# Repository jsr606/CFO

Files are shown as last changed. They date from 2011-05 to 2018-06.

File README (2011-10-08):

source files for the CHEAP, FAT and OPEN project
===========================================================================
more info: http://8bitklubben.dk/project/CFO/
===========================================================================
in this repository you will find code for the CFO synth ("arduino" folder), the CFO tracker ("processing" folder), illustrator files for the acryl casing ("acrylic casing and lasercutter fix for PCB" folder), and CAD files for the hardware design ("eagle" folder)

sound code + hardware design in this project is based on the arduino synthesizer kit by critter and guittari: http://www.critterandguitari.com/content/arduino-synthesizer-kit

PLEASE NOTE:
this is a work in progress: all code and hardware design still consist bugs. dig the glitches! njam njam!

--- enjoy
          _____                    _____                   _______         
         /\    \                  /\    \                 /::\    \        
        /::\    \                /::\    \               /::::\    \       
       /::::\    \              /::::\    \             /::::::\    \      
      /::::::\    \            /::::::\    \           /::::::::\    \     
     /:::/\:::\    \          /:::/\:::\    \         /:::/~~\:::\    \    
    /:::/  \:::\    \        /:::/__\:::\    \       /:::/    \:::\    \   
   /:::/    \:::\    \      /::::\   \:::\    \     /:::/    / \:::\    \  
  /:::/    / \:::\    \    /::::::\   \:::\    \   /:::/____/   \:::\____\ 
 /:::/    /   \:::\    \  /:::/\:::\   \:::\    \ |:::|    |     |:::|    |
/:::/____/     \:::\____\/:::/  \:::\   \:::\____\|:::|____|     |:::|    |
\:::\    \      \::/    /\::/    \:::\   \::/    / \:::\    \   /:::/    / 
 \:::\    \      \/____/  \/____/ \:::\   \/____/   \:::\    \ /:::/    /  
  \:::\    \                       \:::\    \        \:::\    /:::/    /   
   \:::\    \                       \:::\____\        \:::\__/:::/    /    
    \:::\    \                       \::/    /         \::::::::/    /     
     \:::\    \                       \/____/           \::::::/    /      
      \:::\    \                                         \::::/    /       
       \:::\____\                                         \::/____/        
        \::/    /                                          ~~              
         \/____/

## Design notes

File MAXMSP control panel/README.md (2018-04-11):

control panel for the CFO BODYSEQ, HÅRNET (and other teensy based CFOs)
=======================================================================

this dashboard sends the appropriate MIDI commands to the CFO synth to change most sound parameters in a user-friendly way

you will require either max/msp (free trial) or max runtime (free) to run this: http://cycling74.com/downloads/

to get started:
1. connect you CFO
2. click the "Update Lists" button - this will populate the list of possible MIDI inputs and outputs
3. choose: Out: Teensy MIDI
4. make sounds! (please note the control panel does not generate MIDI notes, it only sets up the synthesis engine. to play notes, you either have to do this with the synth itself or via MIDI sequencing from a DAW or something similar)
5. to save or recall presets select bank U/A/B/C (U is user presets, will be saved to CFO EEPROM, and can be restored after power off)

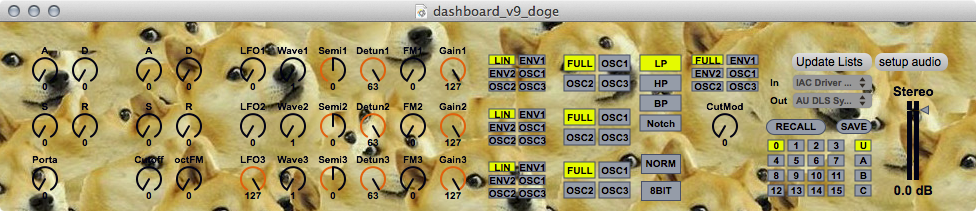
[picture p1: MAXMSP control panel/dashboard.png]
control panel preview


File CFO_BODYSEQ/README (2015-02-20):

CFO BODYSEQ
===========
the CFO BODYSEQ is a step sequencer and synthesizer in one. based on the arduino compatible teensy platform, the CFO BODYSEQ is fully software customizable and ready to jam. the synth is a raw digital acid machine, with an 8 step touch responsive interface based on skin connectivity. make your sweat play for you!
http://vsionhairies.info/

schematics on upverter: https://upverter.com/videomusik/ff5b46c3e927ee1e/CFO-BODYSEQ/

assembly instructions: https://github.com/jsr606/CFO/tree/master/CFO_BODYSEQ/documentation/CFO%20BODYSEQ%203%20button%20version

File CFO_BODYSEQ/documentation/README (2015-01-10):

notes on uploading code to teensy based CFOs

- first install arduino http://arduino.cc/ + this library

- then install teensyduino: https://www.pjrc.com/teensy/teensyduino.html
you don't have to install any of the libraries

- restart arduino

- teensy settings in arduino:
board should be set to "Teensy 3.1"
CPU speed should be set to "96 MHz (overclock)"
USB type should be "MIDI"

- have fun!

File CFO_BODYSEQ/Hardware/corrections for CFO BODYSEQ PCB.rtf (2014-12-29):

corrections for CFO BODYSEQ PCB
===============================
volume knob goes the wrong way
diode D11 should show polarity on print
IC socket should show orientation on print

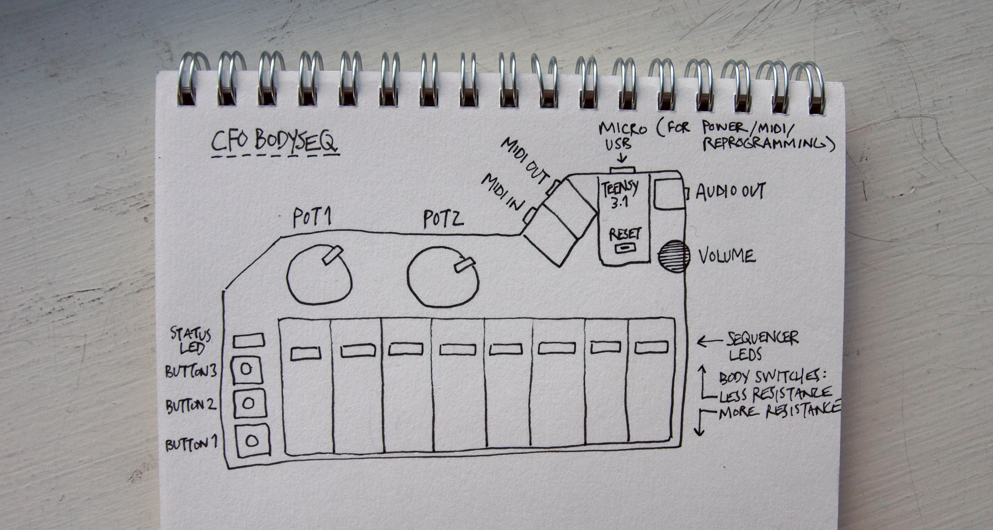
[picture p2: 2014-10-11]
CFO_BODYSEQ/documentation/CFO BODYSEQ 3 button version/manual 3 button version.rtfd/OVERVIEW CFO BODYSEQ 3 button version.JPG

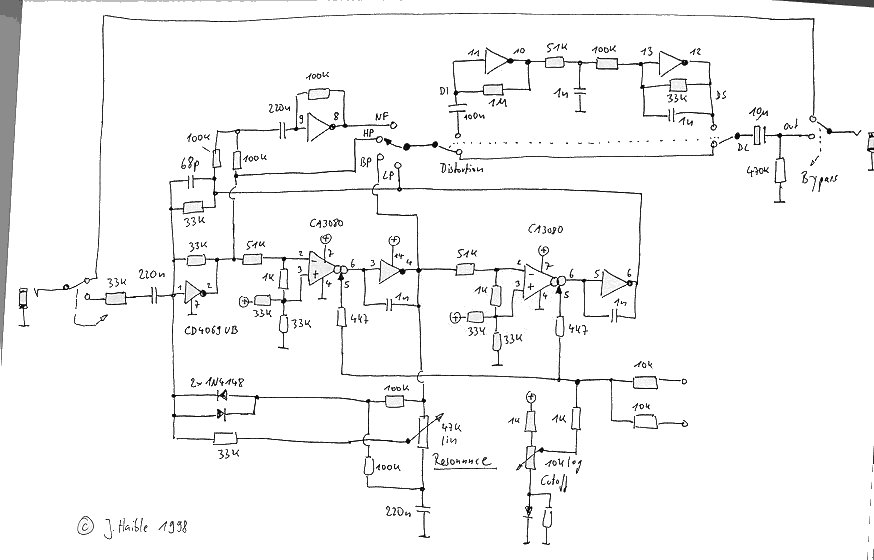
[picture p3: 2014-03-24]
CFO_Haarnet/documentation/Filter Types/hj_wasp.jpg

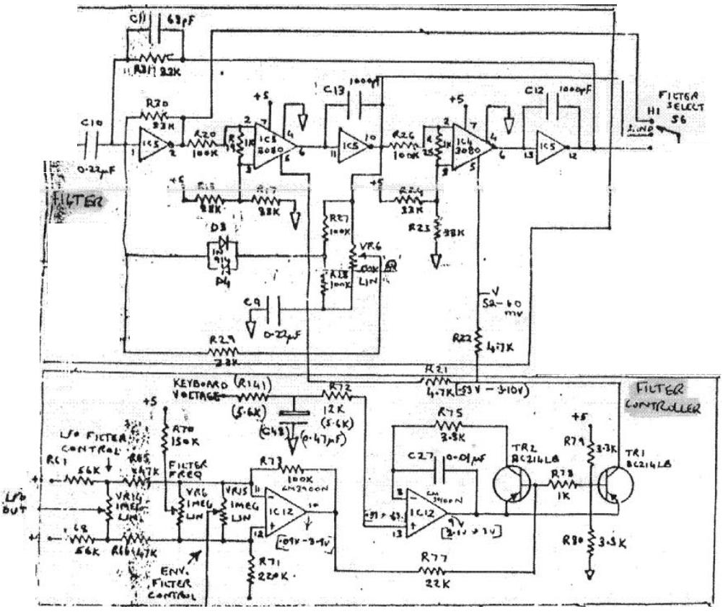
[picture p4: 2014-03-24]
CFO_Haarnet/documentation/Filter Types/wasp_org.jpg

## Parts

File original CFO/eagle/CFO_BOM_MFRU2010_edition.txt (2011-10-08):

CFO partlist - edited by hand, non-parts (pads etcs) removed, non-eagle parts added
==========================================================================================
this version for CFO MFRU edition 2010, manSEDANse workshop 2011, 4/10-2011
==========================================================================================
Exported from CFO rev 1.5_bak_jsr.brd at 6/15/11 21:39 
==========================================================================================
x Part               Value          Package       Library                  Position (mm)         Orientation

x DIST               switch         1X03/90       pinhead                  (140.5 51)            R270
x BASS               switch         1X03/90       pinhead                  (140.5 43.5)          R270

x C2                 22p            C050-025X075  rcl                      (71.1519 72.3128)     R90
x C3                 22p            C050-025X075  rcl                      (55.8893 72.3406)     R90
x C10                10nF           C050-025X075  rcl                      (115.5633 11.3685)    R270
x CL3                33n            C050-025X075  rcl                      (96.15 34.1)          R0
x CL2                47n            C050-025X075  rcl                      (124.85 34)           R0
x C1                 100n           C050-025X075  rcl                      (74.7393 72.2982)     R270
x C4                 100n           C050-025X075  rcl                      (78.092 72.3306)      R270
x C5                 100n           C050-025X075  rcl                      (18.8987 74.8509)     R90
x C8                 100n           C050-025X075  rcl                      (109.9672 11.3168)    R270
x C9                 100n           C050-025X075  rcl                      (126.5078 11.4433)    R90
x CL_IN              2u2            E2,5-6        blushingboy_experimental (125.7 21.6)          R180
x CL4                10u            E2,5-6        blushingboy_experimental (104 29)              R270
x C6                 100u           E3,5-8        rcl                      (11.4949 75.444)      R270
x C7                 100u           E3,5-8        rcl                      (11.4997 65.9713)     R90
x CL5                330u           E2,5-6        blushingboy_experimental (123 28)              R0
x CL6                10u            E2,5-6        blushingboy_experimental (-18 -37)             R0

x CONTRAST           4.7k           TRIM_POT_PTH  SparkFun                 (38.6519 43.9962)     R90
x D1                 1N4004         DO41-10       diode                    (4.3209 76.2091)      R90
x DC1                DC21MMX        DC-21MM       powersupply              (-6.4416 81.6708)     R90
x ENCODER            EC12E_SW       ALPS_EC12E_SW switch-alps              (136.4057 63.7769)    R270
x EXPRESSION_CONTROL PG203J         PG203J        con-hirschmann           (-1.2408 48.6537)     R0
x STYLOPHONE         PG203J         PG203J        con-hirschmann           (139.1984 -0.5876)    R180
x AUDIO_OUT          PG203J         PG203J        con-hirschmann           (139.2529 18.019)     R180
x IC1                ATMEGA         DIL28-3       atmel                    (69.4941 60.211)      R180
x IC3                74HC595N       DIL16         74xx-eu                  (62.255 11.5338)      R270
x IC4                74HC595N       DIL16         74xx-eu                  (74.9049 11.5048)     R90
x IC5                               78XXL         v-reg                    (12.4506 87.9283)     R263
x ICSP               ICSP           2X03          pinhead                  (45.5541 59.4185)     R90
x IR_RX                             1X03          ir-receiver                (-6.9533 68.8385)     R90
x LCD_DISPLAY                       1X16          pinhead                  (69.8556 45.9752)     R0

x LED1                              LED5MM        led                      (11.3766 -6.294)      R270
x LED2                              LED5MM        led                      (19.2176 -3.758)      R270
x LED3                              LED5MM        led                      (27.3046 -6.611)      R270
x LED4                              LED5MM        led                      (34.7606 -6.33)       R270
x LED5                              LED5MM        led                      (42.1086 -3.819)      R270
x LED6                              LED5MM        led                      (49.2836 -6.365)      R270
x LED7                              LED5MM        led                      (55.8776 -3.773)      R270
x LED8                              LED5MM        led                      (62.8946 -6.365)      R270
x LED9                              LED5MM        led                      (70.0966 -6.338)      R270
x LED10                             LED5MM        led                      (77.2646 -3.819)      R270
x LED11                             LED5MM        led                      (84.2116 -6.325)      R270
x LED12                             LED5MM        led                      (90.9066 -3.771)      R270
x LED13                             LED5MM        led                      (97.8016 -6.325)      R270
x LED14                             LED5MM        led                      (104.8966 -3.846)     R270
x LED15                             LED5MM        led                      (112.0916 -6.325)     R270
x LED16                             LED5MM        led                      (119.3866 -6.579)     R270
x PWR_LED                           LED5MM        led                      (35.2058 67.0345)     R90
x STATUS                            LED5MM        led                      (128.7394 50.916)     R90
x IR                                LED5MM        IR led                   (128.6837 44.8888)    R90

x MCP4921                           DIL08         ic-package               (102.9774 10.4479)    R180
x NAV1               DTE6K          DTE6K         switch-misc              (2.2164 33.5436)      R0
x NAV2               DTE6K          DTE6K         switch-misc              (16.9164 5.8436)      R0
x NAV3               DTE6K          DTE6K         switch-misc              (4.4164 18.8436)      R0
x NAV4               DTE6K          DTE6K         switch-misc              (29.9164 18.8436)     R0
x NAV5               DTE6K          DTE6K         switch-misc              (16.9164 18.8436)     R0
x NAV6               DTE6K          DTE6K         switch-misc              (16.9164 31.8436)     R0

x R26                4.7            0207/10       rcl                      (91.8956 60.3816)     R270
x RL1                10             0207/10       rcl                      (123 37.5)            R180
x R7                 47             0207/10       rcl                      (123.3116 47.5153)    R270
x R6                 220            0207/10       rcl                      (19.3044 41.5376)     R0
x R10                220            0207/10       rcl                      (48.2745 20.4162)     R0
x R11                220            0207/10       rcl                      (48.2745 17.9042)     R0
x R12                220            0207/10       rcl                      (48.2745 15.3922)     R0
x R13                220            0207/10       rcl                      (48.2745 12.8802)     R0
x R14                220            0207/10       rcl                      (48.2745 10.3682)     R0
x R15                220            0207/10       rcl                      (48.2745 7.8562)      R0
x R16                220            0207/10       rcl                      (48.2745 5.3442)      R0
x R17                220            0207/10       rcl                      (48.2745 2.5782)      R0
x R18                220            0207/10       rcl                      (88.8855 2.4738)      R180
x R19                220            0207/10       rcl                      (88.8855 4.9858)      R180
x R20                220            0207/10       rcl                      (88.8855 7.4978)      R180
x R21                220            0207/10       rcl                      (88.8855 10.0098)     R180
x R22                220            0207/10       rcl                      (88.8855 12.5218)     R180
x R23                220            0207/10       rcl                      (88.8855 15.0338)     R180
x R24                220            0207/10       rcl                      (88.8855 17.5458)     R180
x R25                220            0207/10       rcl                      (88.8855 20.3118)     R180
x R27                220            0207/10       rcl                      (0.4997 -5.6694)      R180
x R28                220            0207/10       rcl                      (15.7434 -11.7184)    R162.4
x R29                220            0207/10       rcl                      (23.6382 -11.6477)    R162.2
x R30                220            0207/10       rcl                      (31.1198 -11.5191)    R163.7
x R31                220            0207/10       rcl                      (38.198 -11.5505)     R163.5
x R32                220            0207/10       rcl                      (45.213 -11.645)      R163.5
x R33                220            0207/10       rcl                      (52.4307 -11.6626)    R163.5
x R34                220            0207/10       rcl                      (59.3887 -11.7339)    R163.5
x R35                220            0207/10       rcl                      (66.4165 -11.8384)    R163.5
x R36                220            0207/10       rcl                      (73.4096 -11.911)     R163.5
x R37                220            0207/10       rcl                      (80.2467 -11.7583)    R163.5
x R38                220            0207/10       rcl                      (87.3166 -11.7976)    R163.5
x R39                220            0207/10       rcl                      (94.3397 -11.687)     R163.5
x R40                220            0207/10       rcl                      (101.2719 -11.8822)   R163.5
x R41                220            0207/10       rcl                      (108.1028 -11.8279)   R163.5
x R42                220            0207/10       rcl                      (115.035 -11.6232)    R163.5
x R43                220            0207/10       rcl                      (122.0164 -11.5153)   R163.5
x R44                220            0207/10       rcl                      (128.9589 -11.4403)   R163.5
x R45                220            0207/10       rcl                      (135.8551 -11.3387)   R163.5
x R46                220            0207/10       rcl                      (142.7963 -11.194)    R163.5
x R47                220            0207/10       rcl                      (-4.8856 18.3436)     R90
x R48                220            0207/10       rcl                      (8.4004 5.3196)       R270
x R49                220            0207/10       rcl                      (0.1144 10.3196)      R180
x R50                220            0207/10       rcl                      (33.6864 27.6216)     R0
x R51                220            0207/10       rcl                      (25.4324 32.6376)     R270
x R2                 1k             0207/10       rcl                      (29.6208 63.4541)     R270
x R8                 1k             0207/10       rcl                      (97.9502 60.3244)     R90
x R9                 1k             0207/10       rcl                      (94.9682 60.3815)     R90
x R1                 10k            0207/10       rcl                      (120.9879 11.222)     R90
x R5                 10k            0207/10       rcl                      (26.7108 63.5257)     R270
x R3                 10k            0207/10       rcl                      (123.4575 11.1547)    R270
x R52                10k            0207/10       rcl                      (-6.0524 33.7524)     R270
x R53                10k            0207/10       rcl                      (130.1744 -1.0556)    R90
x R54                10k            0207/10       rcl                      (7.9032 48.6537)      R90
x RL2                10k            0207/10       rcl                      (106.5 34)            R180
x R4                 1M             0207/10       rcl                      (118.469 11.157)      R270

x RX_ON/OFF                         1X03/90       pinhead                  (-2.5617 60.6615)     R90
x S1                                B3F-10XX      switch-omron             (35.1588 73.8796)     R180
x U$1                LM386          LM386         blushingboy_experimental (108 24)              R0
x USB-TTL                           1X06          pinhead                  (72.5876 82.5212)     R173
x XTAL               16mhz          QS            special                  (63.4763 72.233)      R180
==========================================================================================
non-eagle parts
==========================================================================================
x socket for atmega328
x cooling pad for voltage regulator
x knob for encoder
x top for knob
x 3 jumpers
x tiny 10k potentiometer for volume control
x male pin headers for LCD display
x female pin headers for LCD display
==========================================================================================

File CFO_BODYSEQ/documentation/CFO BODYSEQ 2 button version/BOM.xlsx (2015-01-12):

CFO BODYSEQ 2 BUTTON VERSION BILL OF MATERIALS
Reference | Part Description | Qty | note
AUDIO, MIDI IN, MIDI OUT | Science Friction CFO Minijack (https://upverter.com/parts/part/fa8eeb0d68dda8a9) | 3 | mini jack. NB: from special china supply
C1 | Multicomp MCPBSFC-1J104KA45 (https://upverter.com/parts/part/f3762bc8e220dfd9) | 1 | small cap.
C2 | Lelon SEA101M1CBK-0607P (Radial (large) footprint) | 1 | large radial cap.
D1, D2, D3, D4, D5, D6, D7, D8, D9, D10 | Panasonic LN842RPX | 10 | LED
D11 | Vishey 1N4148 (https://upverter.com/parts/part/6b14a46a102bcce9) | 1 | diode
IC1 | PJRC.com Teensy 3.1 (https://upverter.com/parts/part/7ecd58a203736804) | 1 | teensy
male pin header , 5 pins |  | 1
female pin header , 5 pins |  | 1
male pin header , 14 pins |  | 2
female pin header , 14 pins |  | 2
IC2 | Microchip MCP6002-I/P (https://upverter.com/parts/part/4395652a2997a55d) | 1 | IC
IC2 |  | 1 | IC socket
POT1, POT2 | TT Electronics P120PK-Y25BR10K (https://upverter.com/parts/part/ce6e7634d2037d50) | 2 | pots
POT1, POT2 |  | 2 | knobs for potentiometer
R1 - R10 | Generic Resistor (120 ohm) | 10 | LED resistors
R11, R12, R13, R14, R15, R16, R17, R18, R19, R20 | Generic Resistor (10k) | 10 | bodyswitch pulldown + op amp resistors
R21 | BI Technologies 91AR50KLF (https://upverter.com/parts/part/89d94565944c1fdd) | 1 | thumbwheel pot
R22 | Generic Resistor (1k) (Axial footprint) | 1 | color code: brown, black, red
S1, S2, | ALPS SKRGAFD010 (https://upverter.com/parts/part/52c025ccc06d267c) | 2 | tactile switches

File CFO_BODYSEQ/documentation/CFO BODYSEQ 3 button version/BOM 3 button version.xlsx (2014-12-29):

CFO BODYSEQ (3 button version) BILL OF MATERIALS
Reference | Part Description | Qty | note
AUDIO, MIDI IN, MIDI OUT | Science Friction CFO Minijack (https://upverter.com/parts/part/fa8eeb0d68dda8a9) | 3 | mini jack. NB: from special china supply | X
C1 | Multicomp MCPBSFC-1J104KA45 (https://upverter.com/parts/part/f3762bc8e220dfd9) | 1 | small cap. | X
C2 | Lelon SEA101M1CBK-0607P (Radial (large) footprint) | 1 | large radial cap. | X
D1 | Panasonic LN842RPX | 1 | LED | X
D2, D3, D4, D5, D6, D8, D9, D10 | Panasonic LN842RPX | 8 | LED | X
D11 | Vishey 1N4148 (https://upverter.com/parts/part/6b14a46a102bcce9) | 1 | diode | X
IC1 | PJRC.com Teensy 3.1 (https://upverter.com/parts/part/7ecd58a203736804) | 1 | teensy
male pin header , 5 pins |  | 1 | male pin headers | X
female pin header , 5 pins |  | 1 | female pin headers | X
male pin header , 14 pins |  | 2 | male pin headers | X
female pin header , 14 pins |  | 2 | female pin headers | X
IC2 | Microchip MCP6002-I/P (https://upverter.com/parts/part/4395652a2997a55d) | 1 | IC | X
IC2 |  | 1 | IC socket | X
POT1, POT2 | TT Electronics P120PK-Y25BR10K (https://upverter.com/parts/part/ce6e7634d2037d50) | 2 | pots | X
POT1, POT2 |  | 2 | knobs for potentiometer | X
R1 - R9 | Generic Resistor (120 ohm) | 9 | LED resistors | X
R11, R12, R13, R14, R15, R16, R17, R18 | Generic Resistor (10k) | 8 | bodyswitch pulldown resistors | X
R19 | Generic Resistor (10k) (Axial footprint) | 1 | color code: yellow, purple, orange
R20 | Generic Resistor (10k) (Axial footprint) | 1 | resistor | X
R21 | BI Technologies 91AR50KLF (https://upverter.com/parts/part/89d94565944c1fdd) | 1 | thumbwheel pot | X
R22 | Generic Resistor (1k) (Axial footprint) | 1 | color code: brown, black, red
S1, S2, S3 | ALPS SKRGAFD010 (https://upverter.com/parts/part/52c025ccc06d267c) | 3 | tactile switches | X

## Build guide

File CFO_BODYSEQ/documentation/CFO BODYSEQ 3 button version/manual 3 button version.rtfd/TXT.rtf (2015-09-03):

CFO BODYSEQUENCER (3 button version) OPERATIONS MANUAL

¬

press body switches to play notes:
harder press / moist fingers give higher pitch

press more body switches for arpeggiator mode:
while arpeggiator is playing, pot2 changes arpeggiator speed

push button 1:
start/stop sequencer

while holding button 1:
bodyswitches:
enter notes in sequencer

while holding button 2:
bodyswitches:
erase notes in sequencer
pot 1:
sequencer speed

while holding button 3:
bodyswitches:
change sequencer bank (0-7)
pot 1:
change octave
pot 2:
change preset

while holding button 1 AND button 3:
bodyswitches:
select active sequencer slice

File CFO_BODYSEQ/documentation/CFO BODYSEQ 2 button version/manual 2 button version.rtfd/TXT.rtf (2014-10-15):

CFO BODYSEQUENCER (2 button version) OPERATIONS MANUAL

¬

while holding button 1:
bodyswitches:
enter notes in sequencer

while holding button 2:
bodyswitches:
erase notes in sequencer
pot 1:
sequencer speed

while holding button 1 AND button 2:
bodyswitches:
change sequencer bank (0-7)
pot 1:
change octave
pot 2:
change preset

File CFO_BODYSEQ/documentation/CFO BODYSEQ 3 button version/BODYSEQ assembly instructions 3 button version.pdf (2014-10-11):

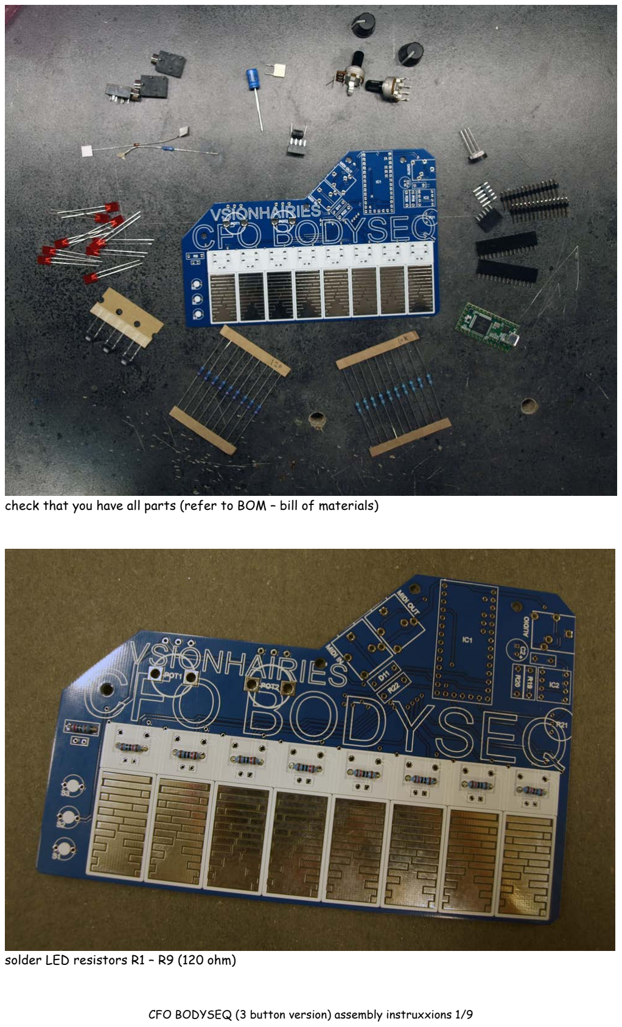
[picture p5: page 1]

CFO BODYSEQ (3 button version) assembly instruxxions 1/9 check that you have all parts (refer to BOM – bill of materials)

solder LED resistors R1 – R9 (120 ohm)

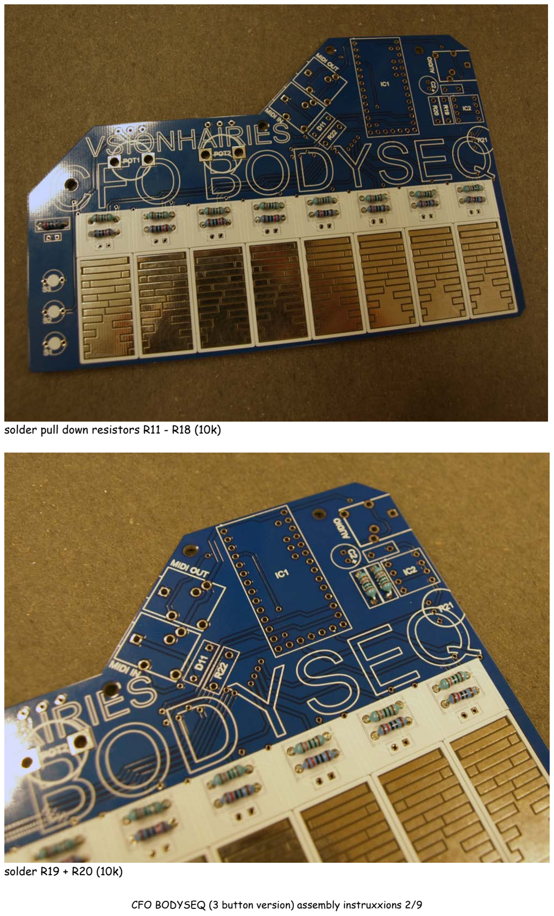
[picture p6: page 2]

solder pull down resistors R11 - R18 (10k)

solder R19 + R20 (10k)

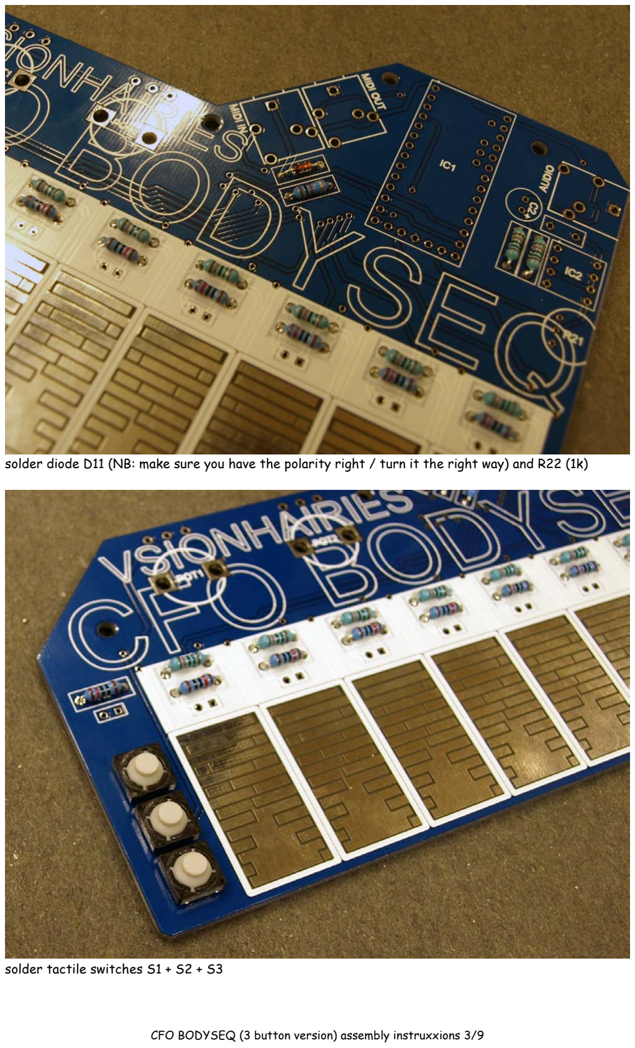
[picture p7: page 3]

solder diode D11 (NB: make sure you have the polarity right / turn it the right way) and R22 (1k)

solder tactile switches S1 + S2 + S3

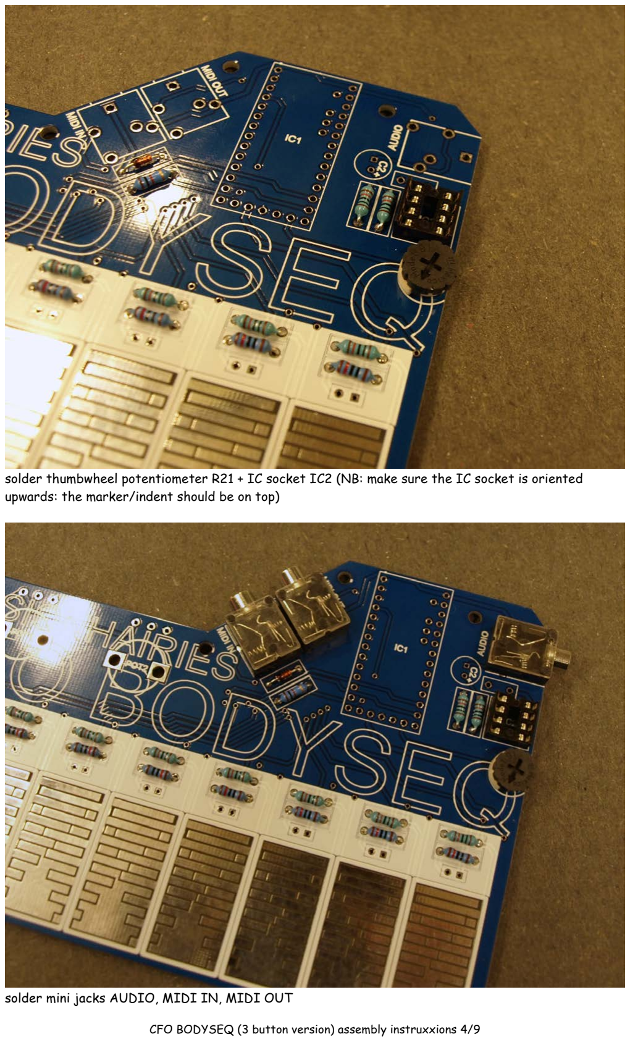
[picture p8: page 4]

solder thumbwheel potentiometer R21 + IC socket IC2 (NB: make sure the IC socket is oriented upwards: the marker/indent should be on top)

solder mini jacks AUDIO, MIDI IN, MIDI OUT

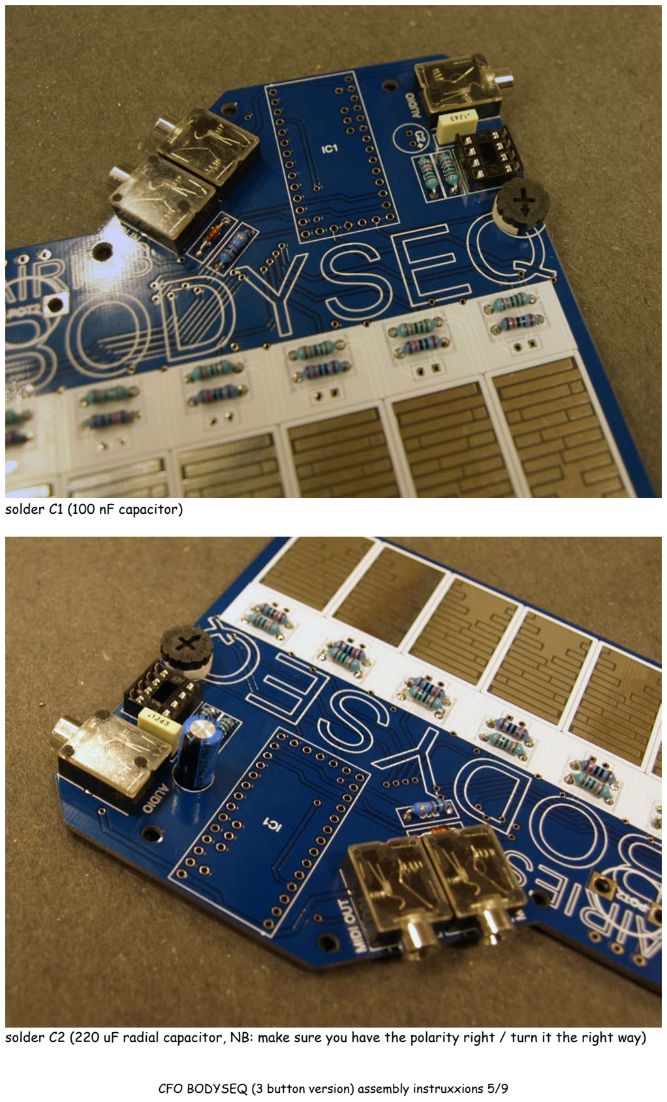
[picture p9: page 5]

solder C1 (100 nF capacitor)

solder C2 (220 uF radial capacitor, NB: make sure you have the polarity right / turn it the right way)

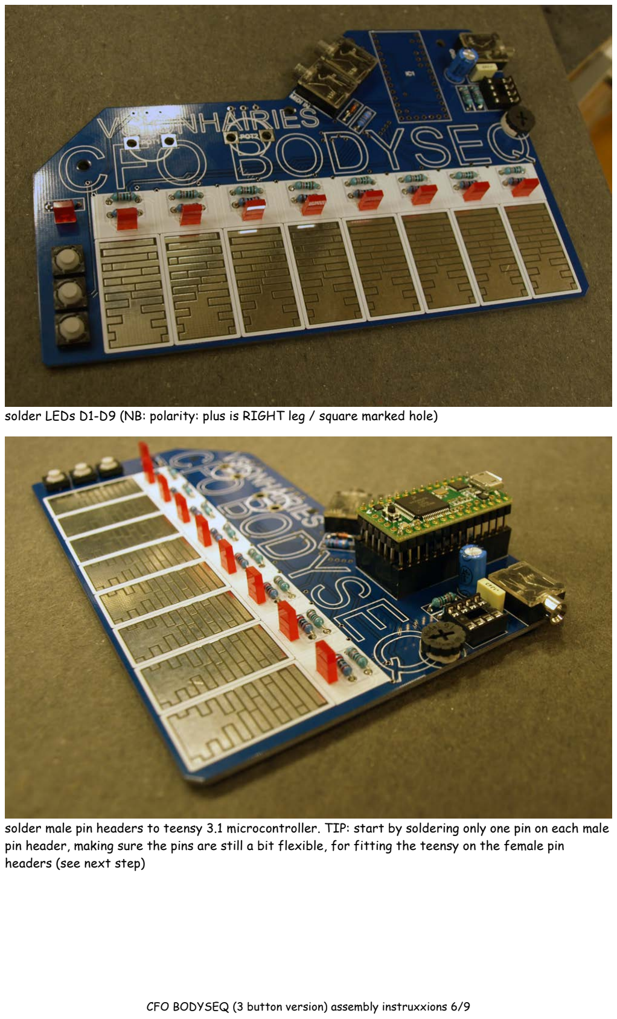
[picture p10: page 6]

solder LEDs D1-D9 (NB: polarity: plus is RIGHT leg / square marked hole)

solder male pin headers to teensy 3.1 microcontroller. TIP: start by soldering only one pin on each male pin header, making sure the pins are still a bit flexible, for fitting the teensy on the female pin headers (see next step)

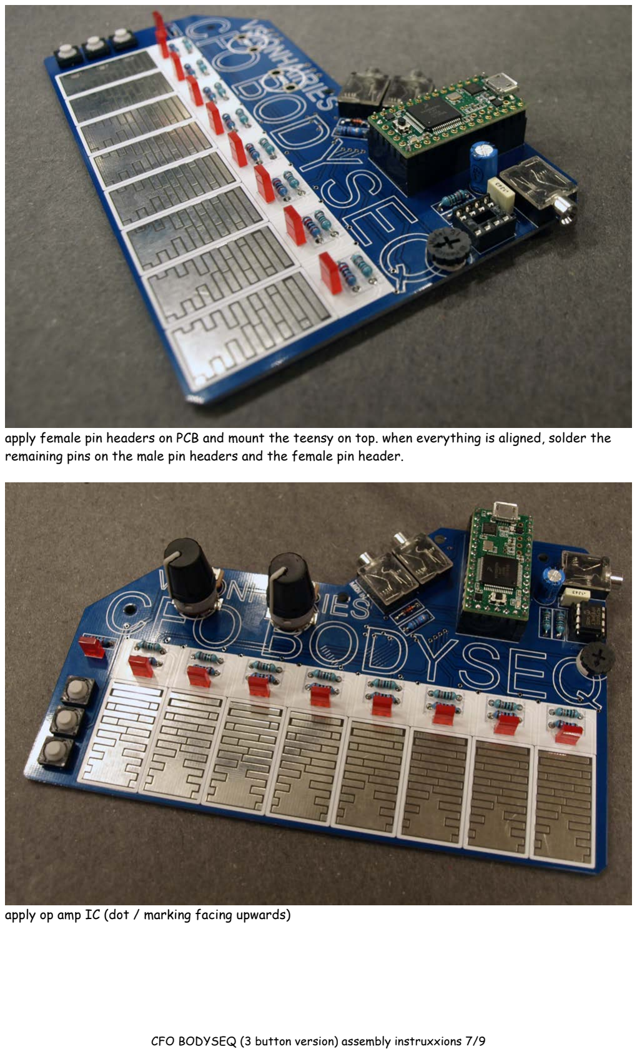
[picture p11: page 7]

apply female pin headers on PCB and mount the teensy on top. when everything is aligned, solder the remaining pins on the male pin headers and the female pin header.

apply op amp IC (dot / marking facing upwards)

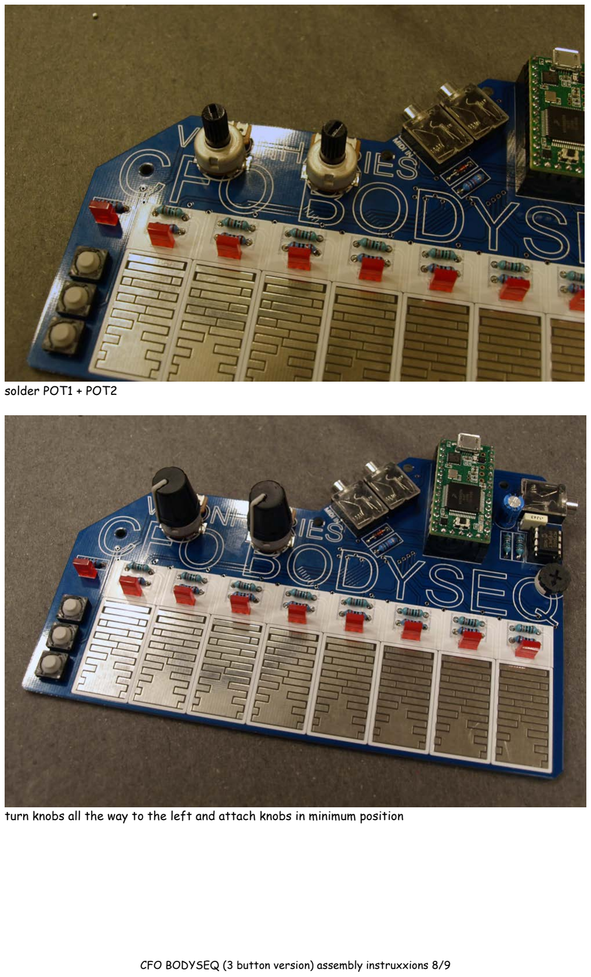
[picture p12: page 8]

solder POT1 + POT2

turn knobs all the way to the left and attach knobs in minimum position

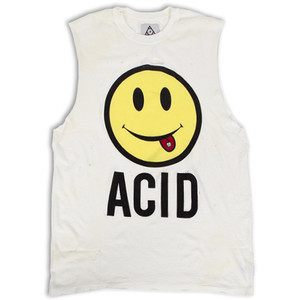
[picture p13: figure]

get dressed. its ACID TIME!

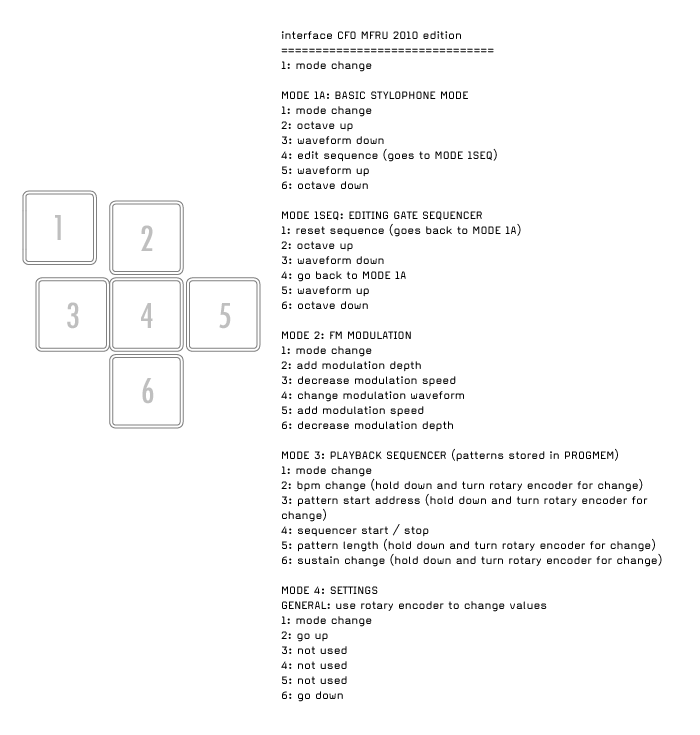
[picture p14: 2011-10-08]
original CFO/documentation/control-manual.png

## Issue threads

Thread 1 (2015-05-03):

same color resistors :(

00alis, 2015-05-03:
hello @jsr606!
for your next rounds of kits you might consider using one 4-stripes and one 5-stripes resistor.
You now deliver both 5-stripes, unfortunately 10K resistors have the same stripes but mirrored compared to 120 resistors, so we soldered them wrong and had to unsolder them all.

just a suggestion!
best <3

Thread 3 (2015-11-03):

CFO_BODYSEQ_3buttons_arp missing lastNote

kritzikratzi, 2015-11-03:
variable should be called lastNote, not lastKey in line 79:

https://github.com/jsr606/CFO/blob/master/CFO_BODYSEQ/Arduino/experimental/CFO_BODYSEQ_3buttons_arp/CFO_BODYSEQ_3buttons_arp.ino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

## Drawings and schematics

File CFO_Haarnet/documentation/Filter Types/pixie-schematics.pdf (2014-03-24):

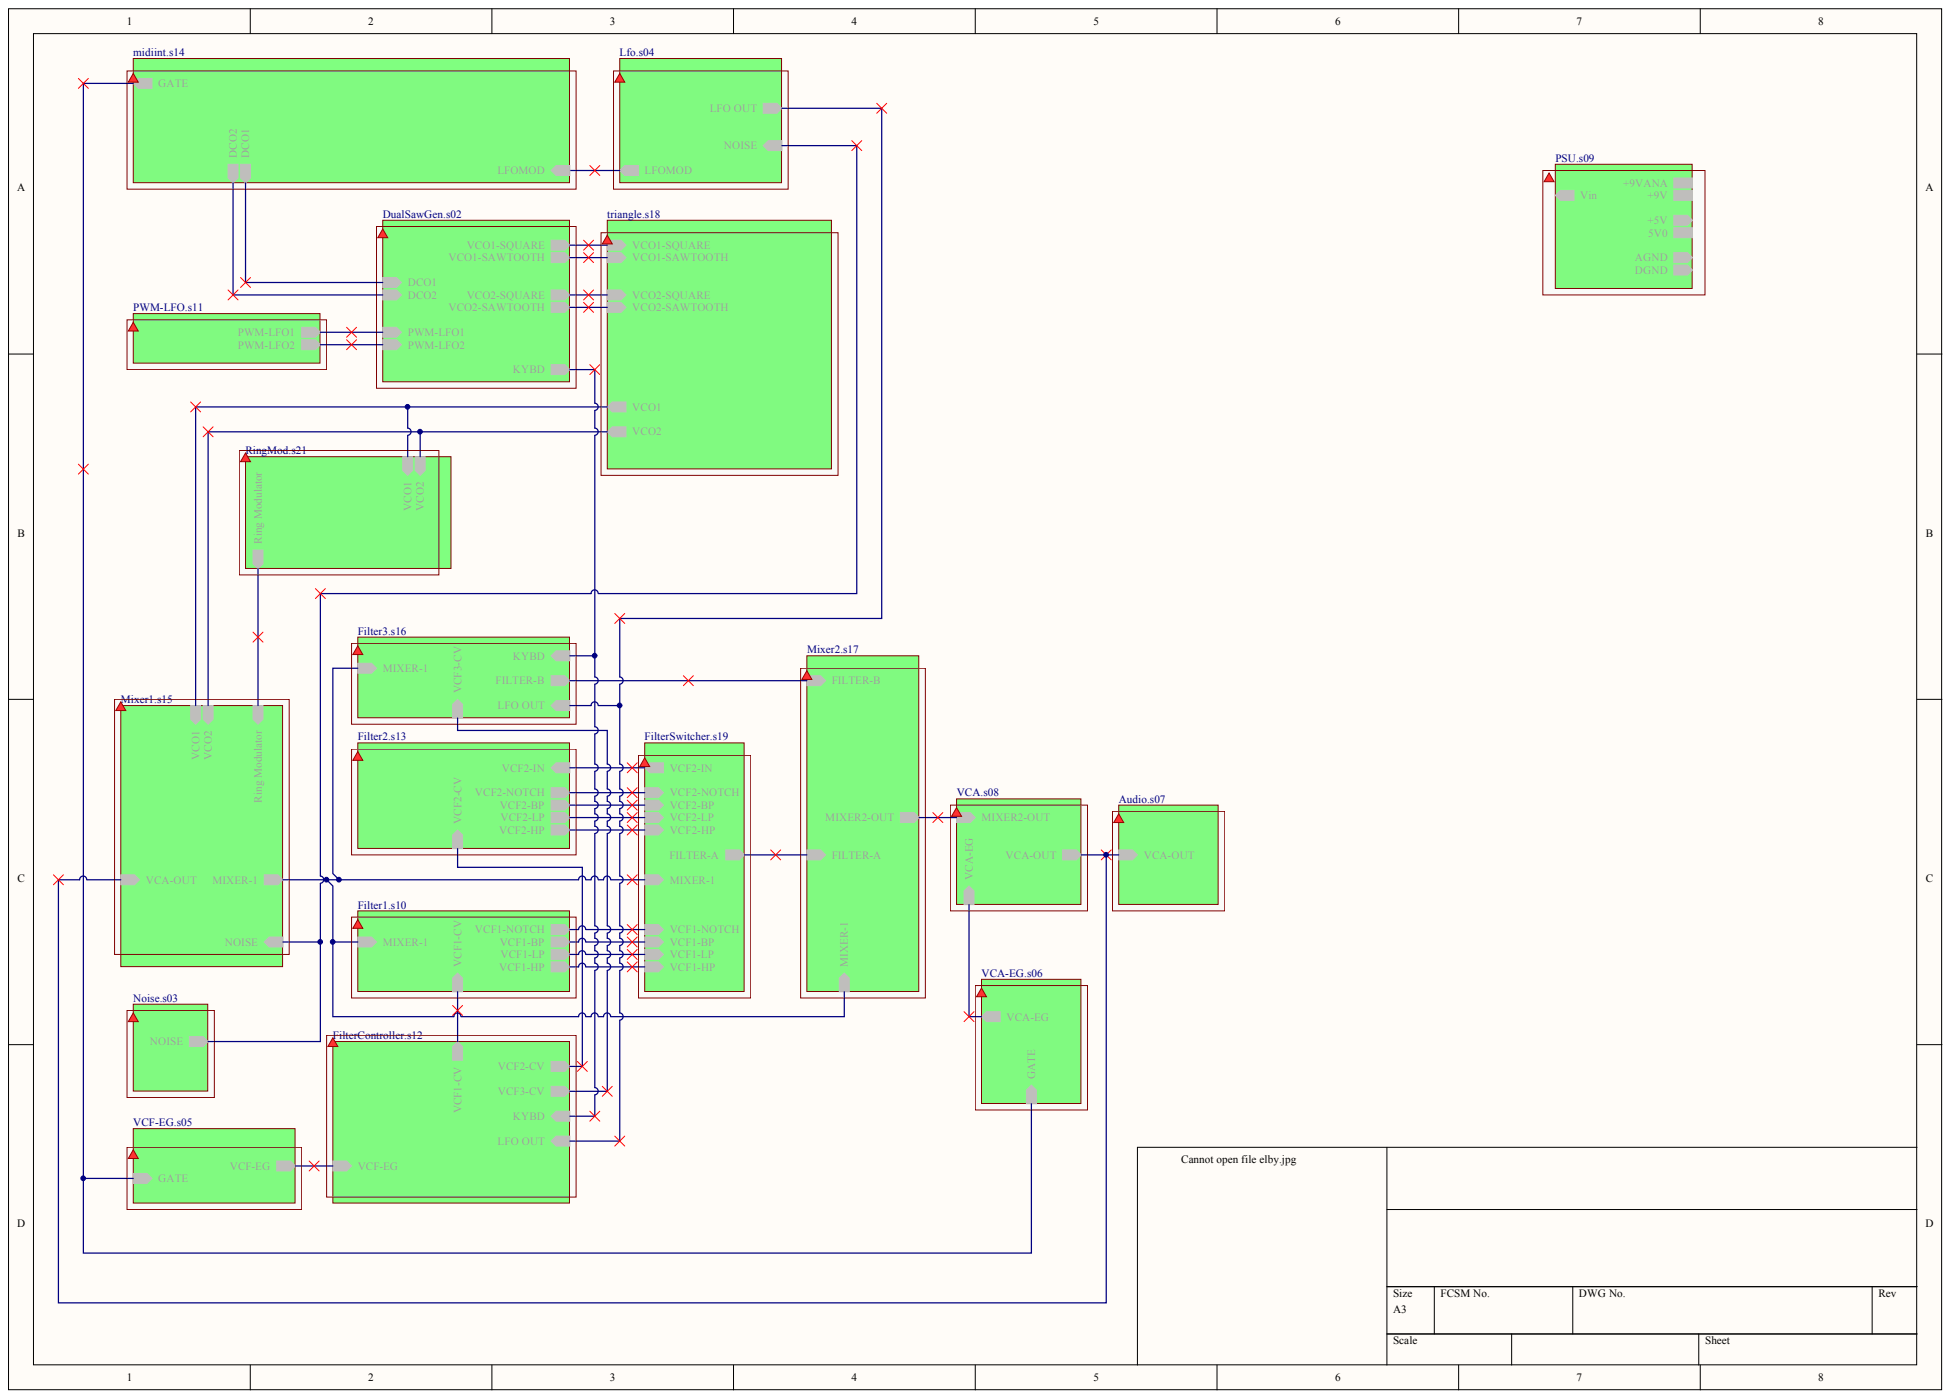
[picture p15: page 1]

LFOMOD | | LFO OUT

NOISE

LFOMOD

DualSawGen.s02 | triangle.s18

MIXER2-OUT

VCA-OUT MIXER-1 | FILTER-A MIXER-1 VCF1-NOTCH VCF1-BP VCF1-LP VCF1-HP | FILTER-A | VCA-OUT

Filter1.s10

MIXER-1 | VCF1-NOTCH VCF1-BP VCF1-LP VCF1-HP

VCA-EG.s06

VCA-EG

Cannot open file elby.jpg

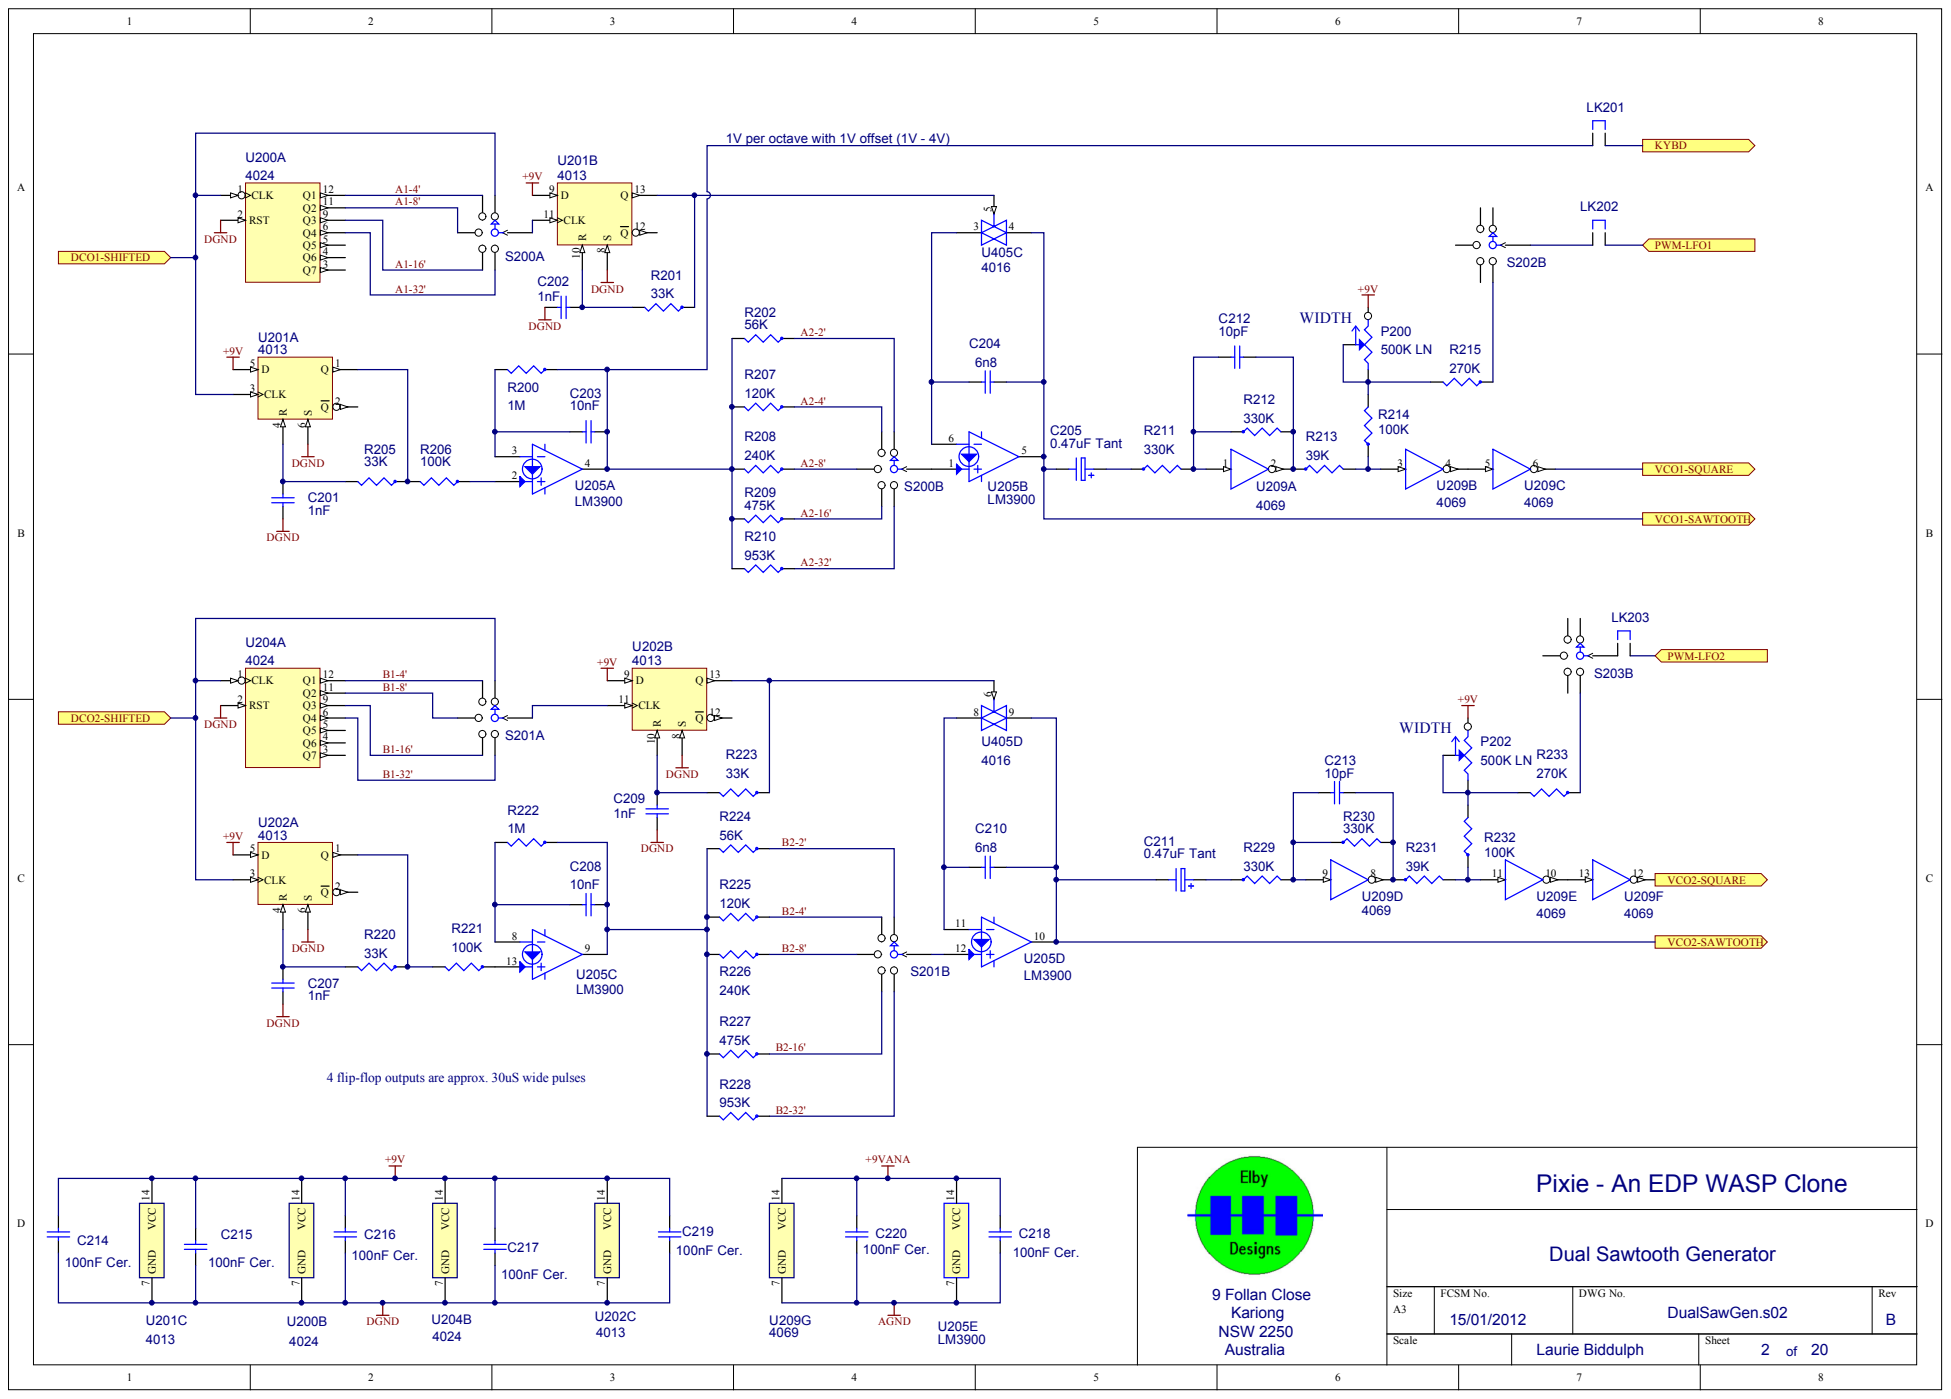
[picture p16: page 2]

1V per octave with 1V offset (1V - 4V)

4 flip-flop outputs are approx. 30uS wide pulses

Pixie - An EDP WASP Clone

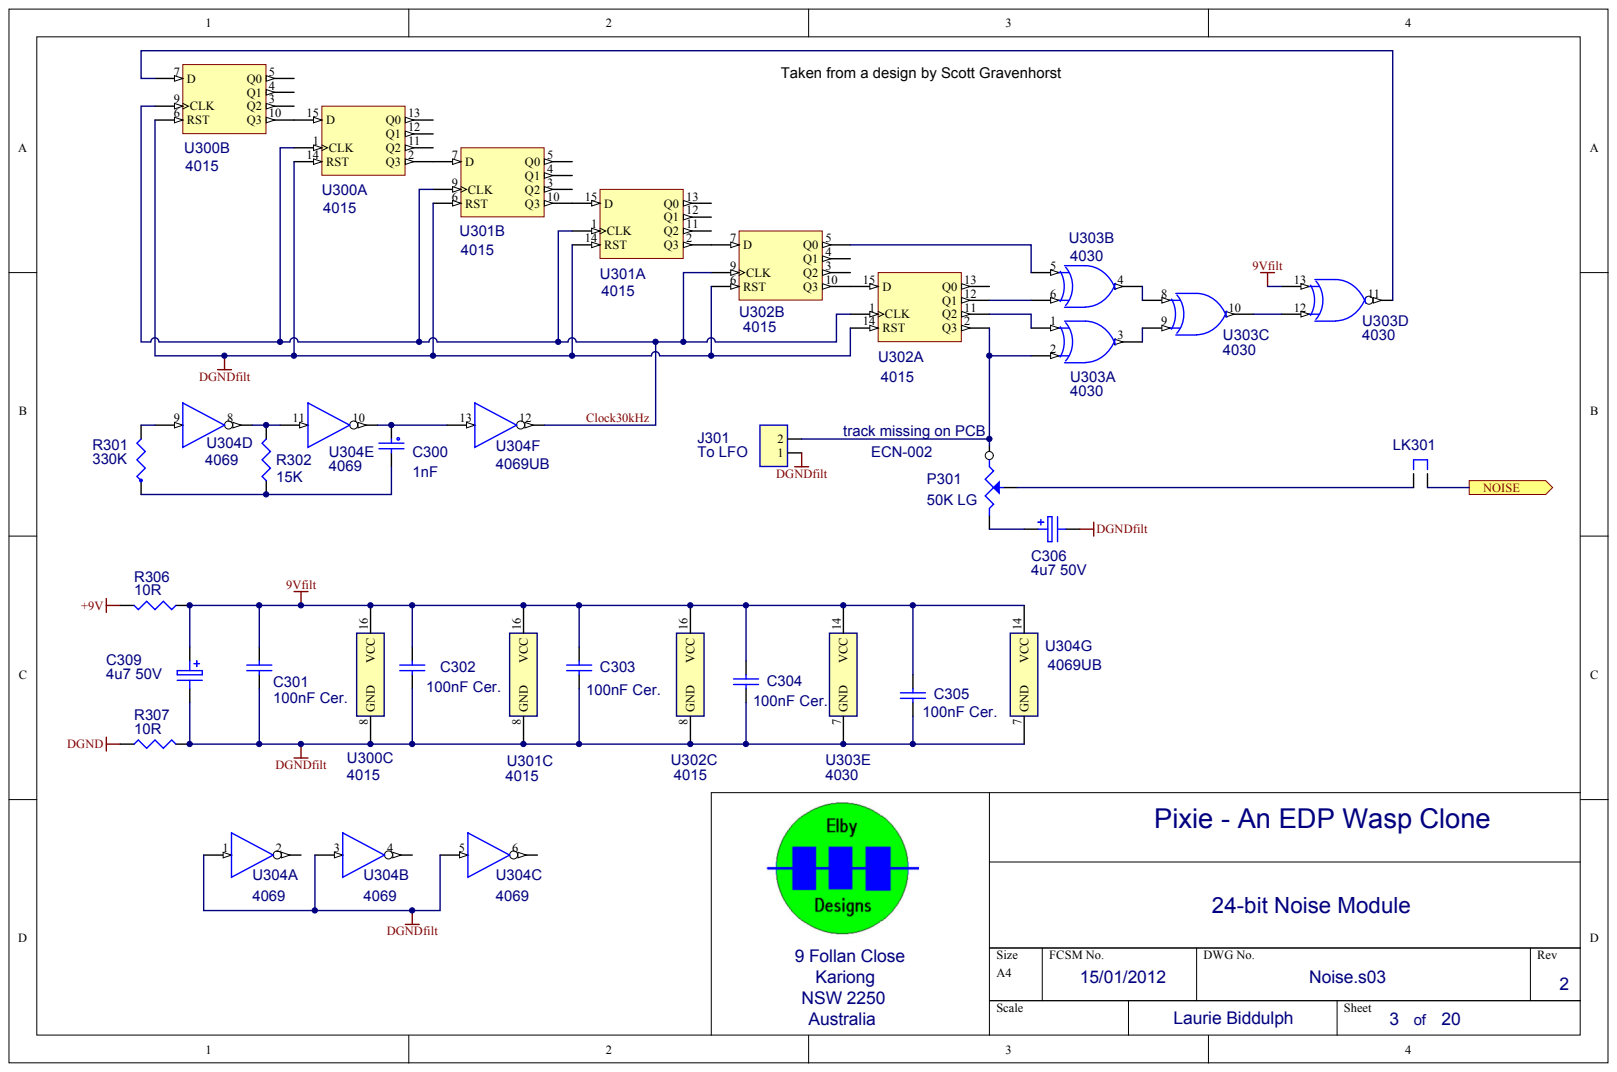
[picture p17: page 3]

Taken from a design by Scott Gravenhorst

RST 6

CLK 1

4015 | RST 14

track missing on PCB
ECN-002

Pixie - An EDP Wasp Clone

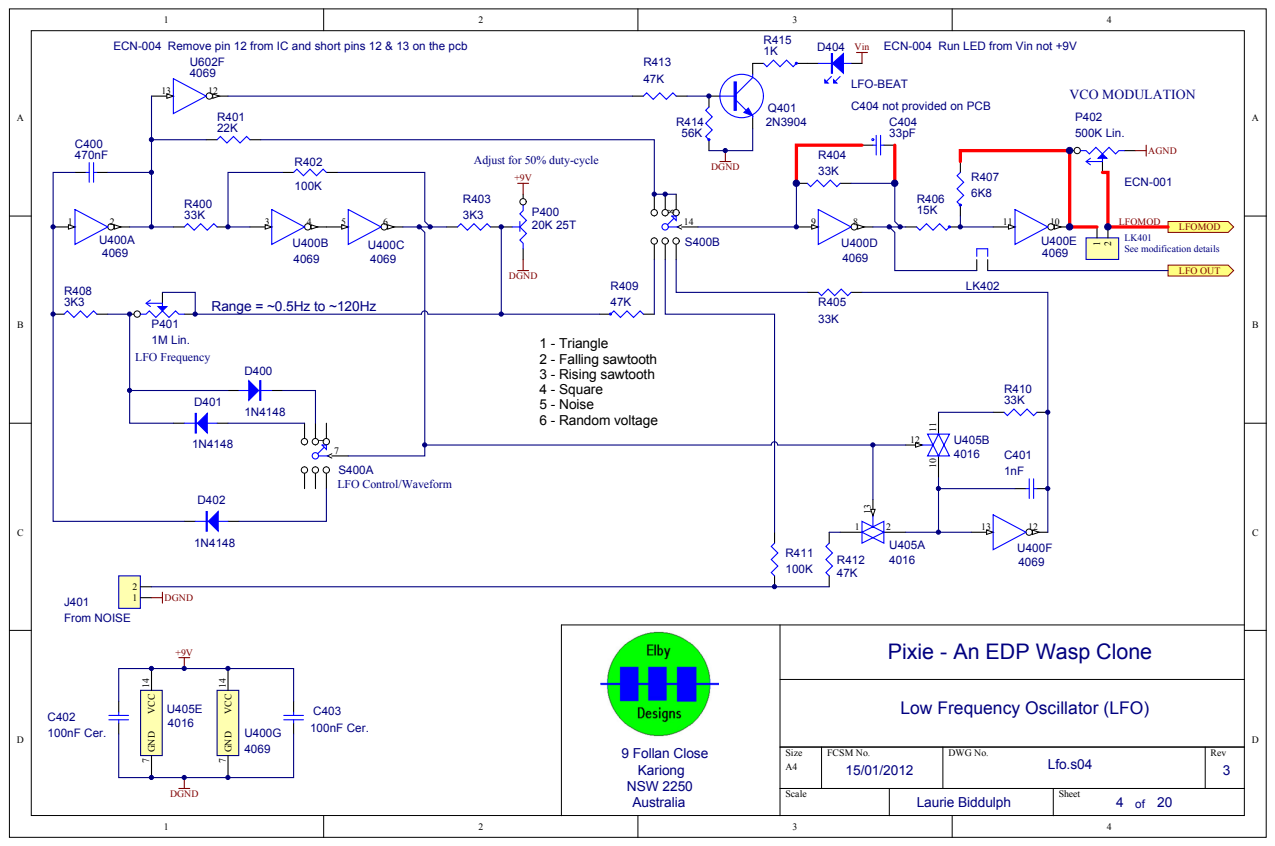
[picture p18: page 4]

C404 not provided on PCB

Adjust for 50% duty-cycle

Range = ~0.5Hz to ~120Hz

P401 1M Lin. LFO Frequency | | D400

Pixie - An EDP Wasp Clone

Low Frequency Oscillator (LFO)

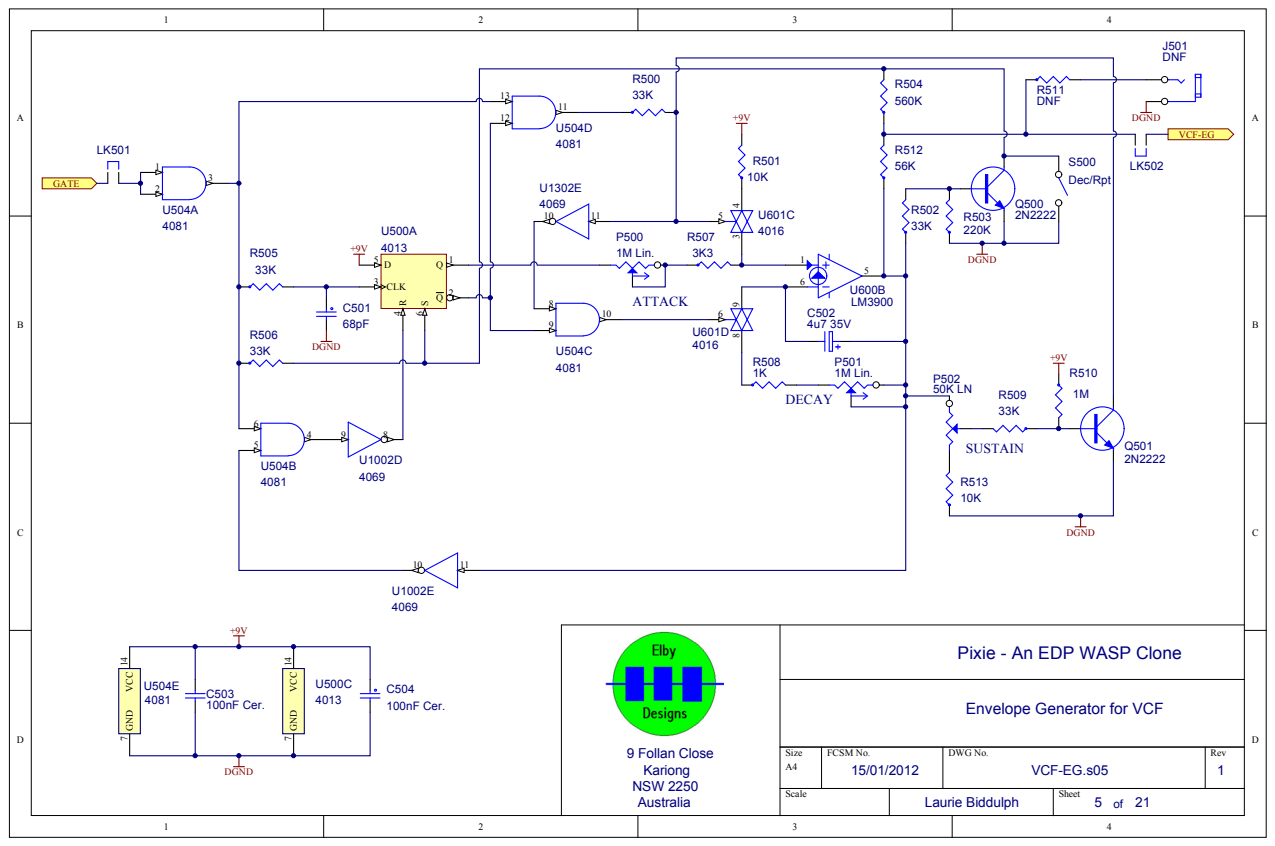
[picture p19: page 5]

CLK 3
Q | 2 R 4

Pixie - An EDP WASP Clone

Envelope Generator for VCF

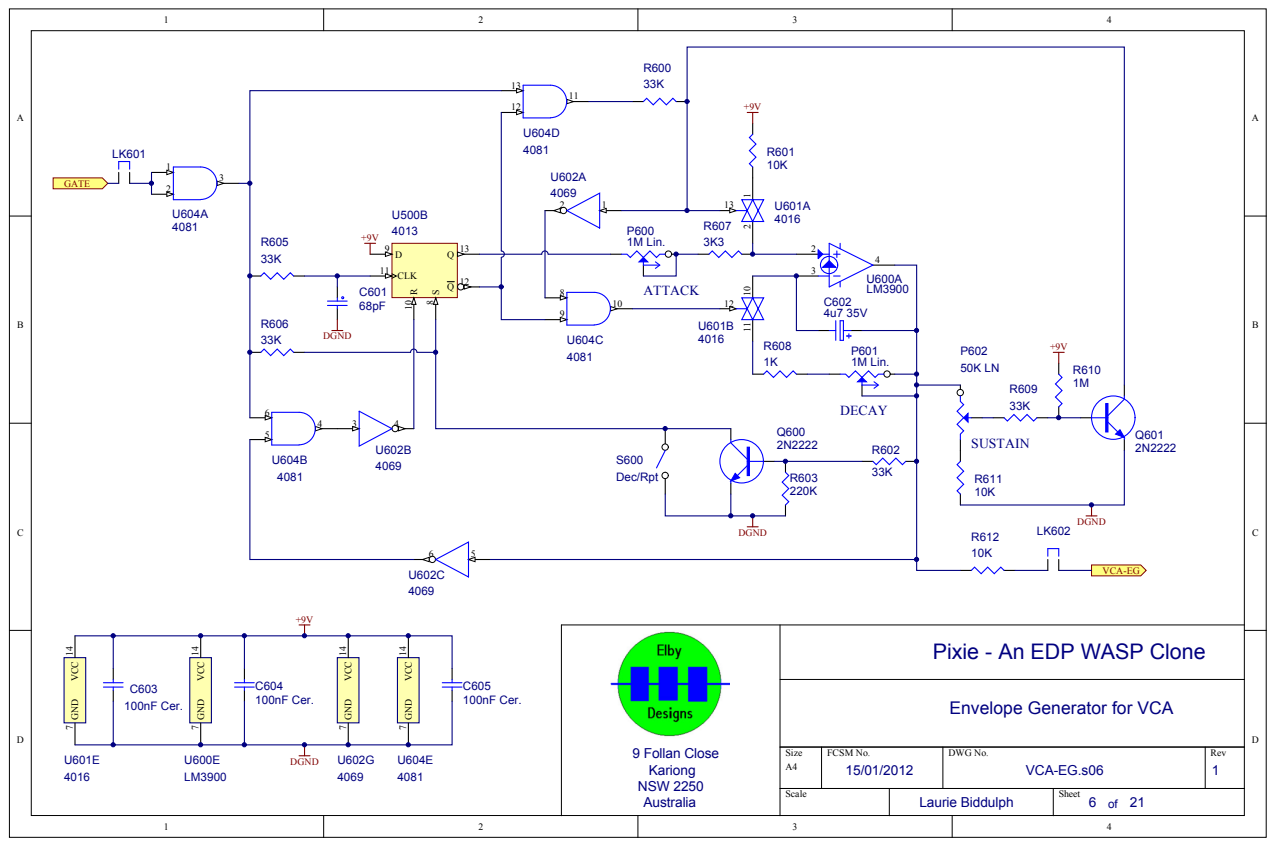
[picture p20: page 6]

Pixie - An EDP WASP Clone

Envelope Generator for VCA

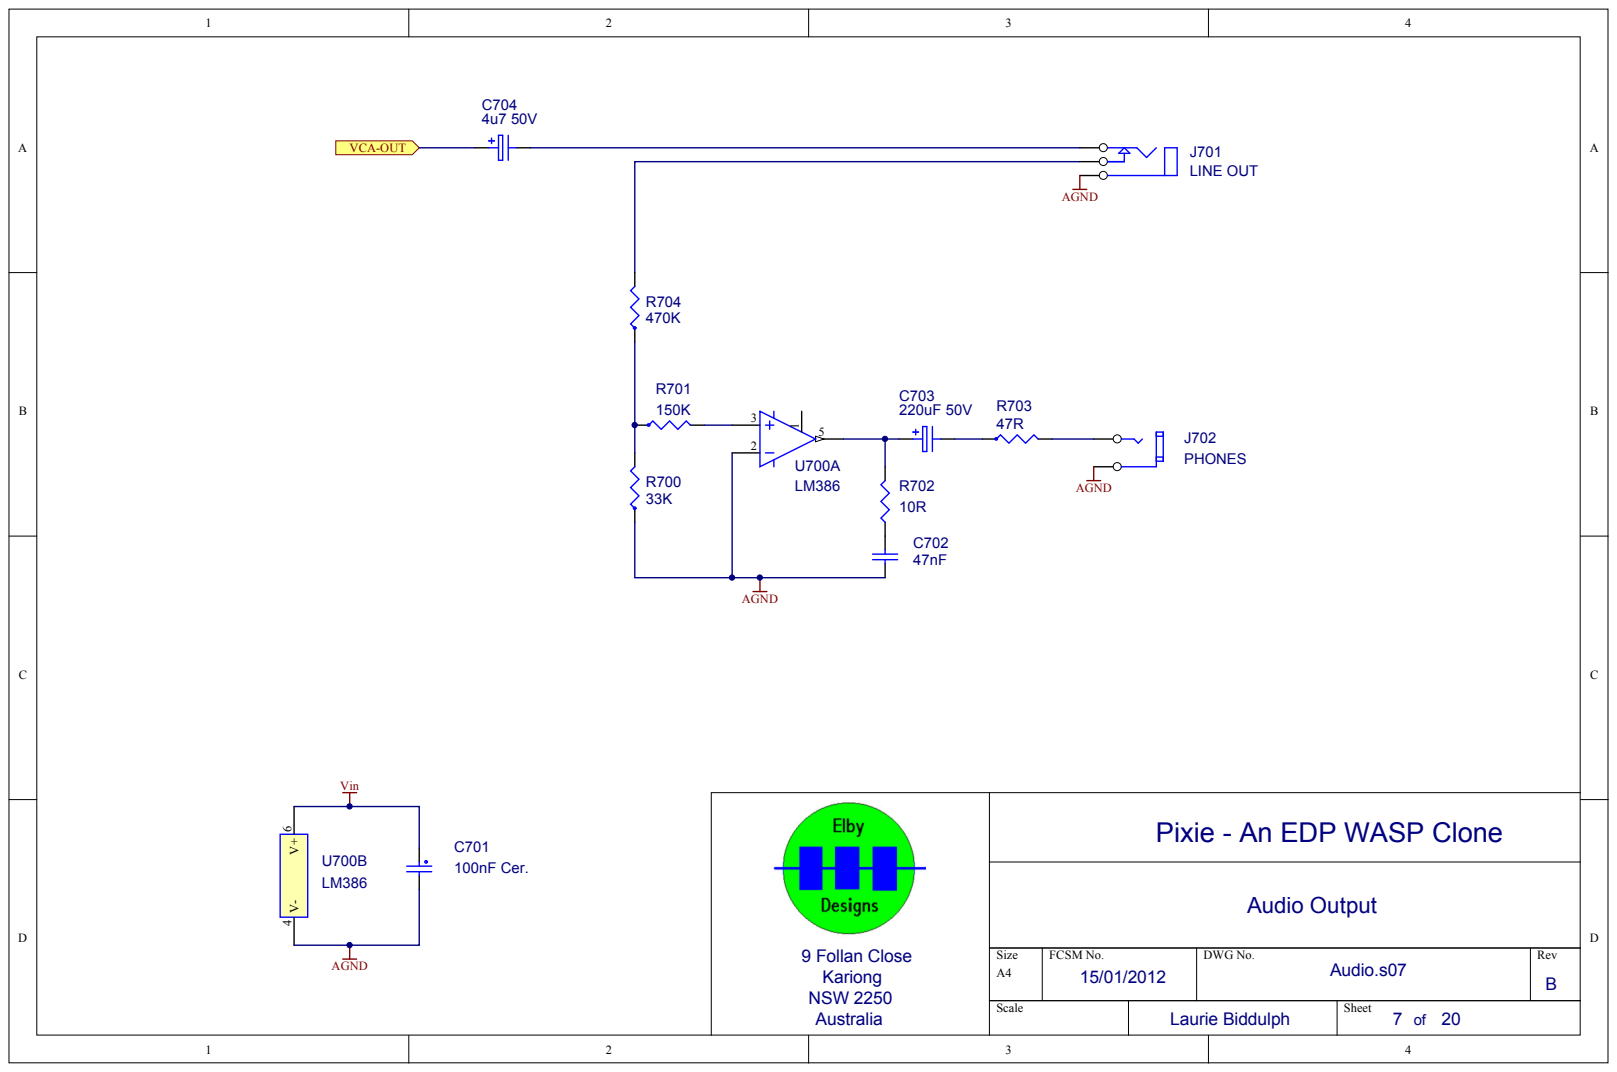
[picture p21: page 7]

Pixie - An EDP WASP Clone

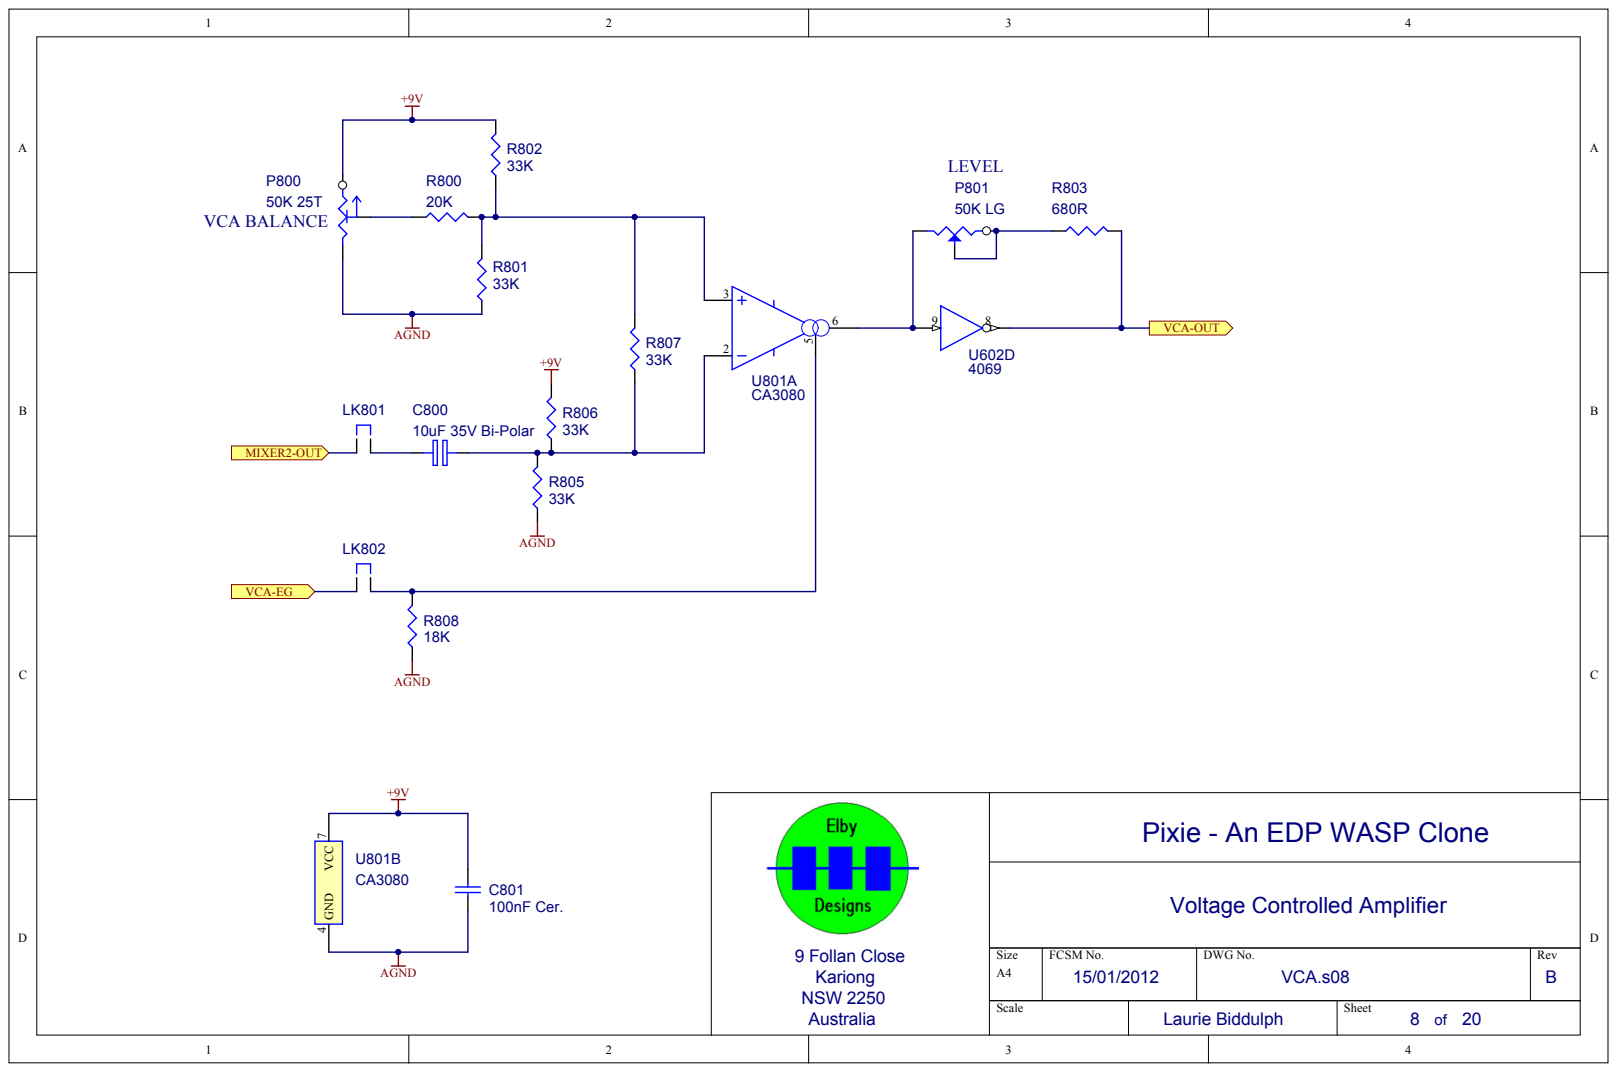
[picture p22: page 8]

Pixie - An EDP WASP Clone

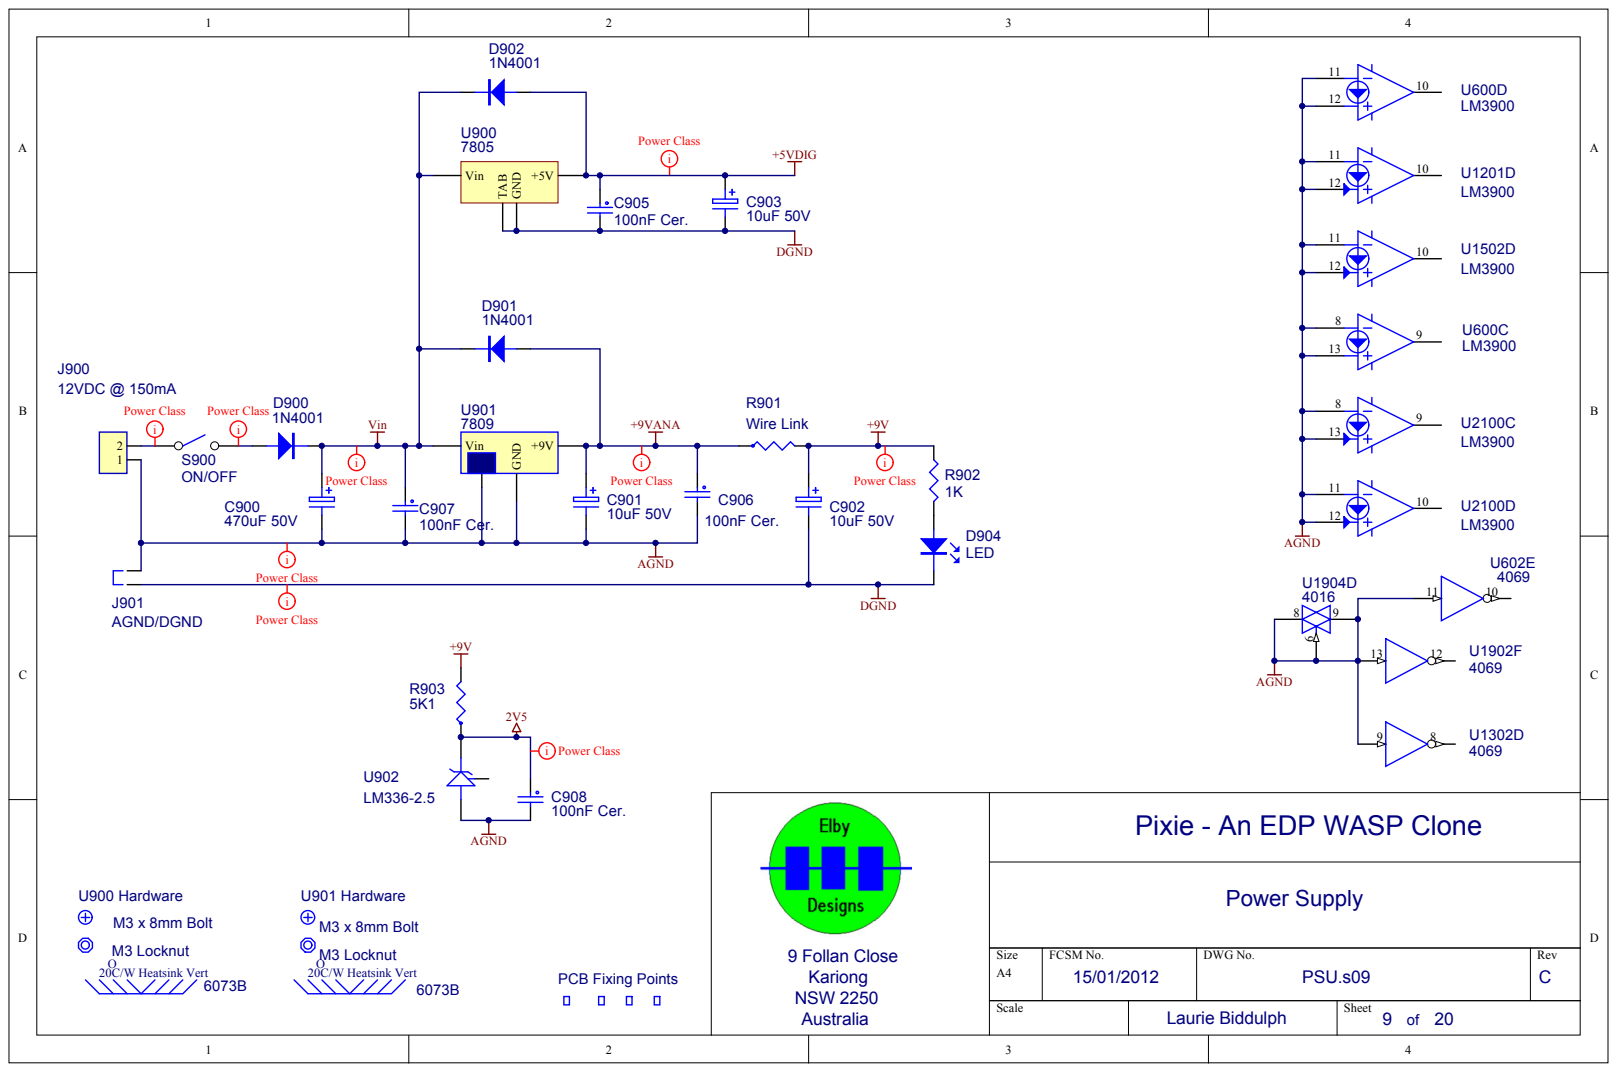
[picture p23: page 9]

470uF 50V | 100nF Cer.

Pixie - An EDP WASP Clone

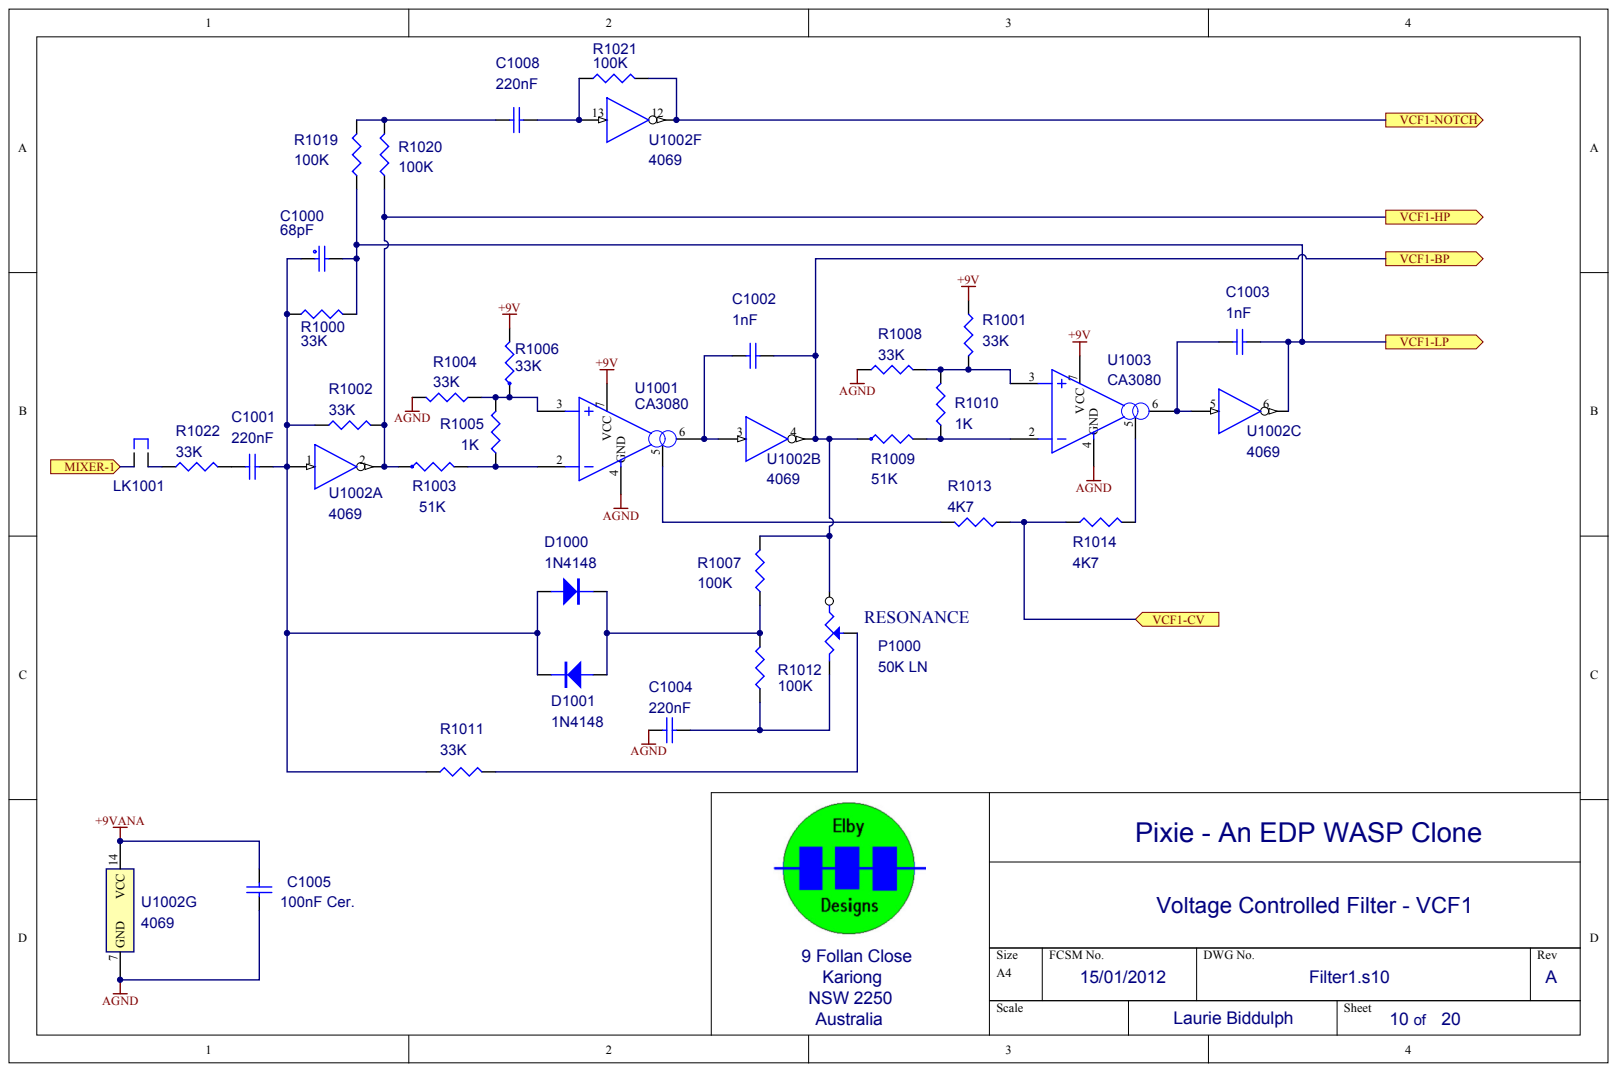
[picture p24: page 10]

Pixie - An EDP WASP Clone

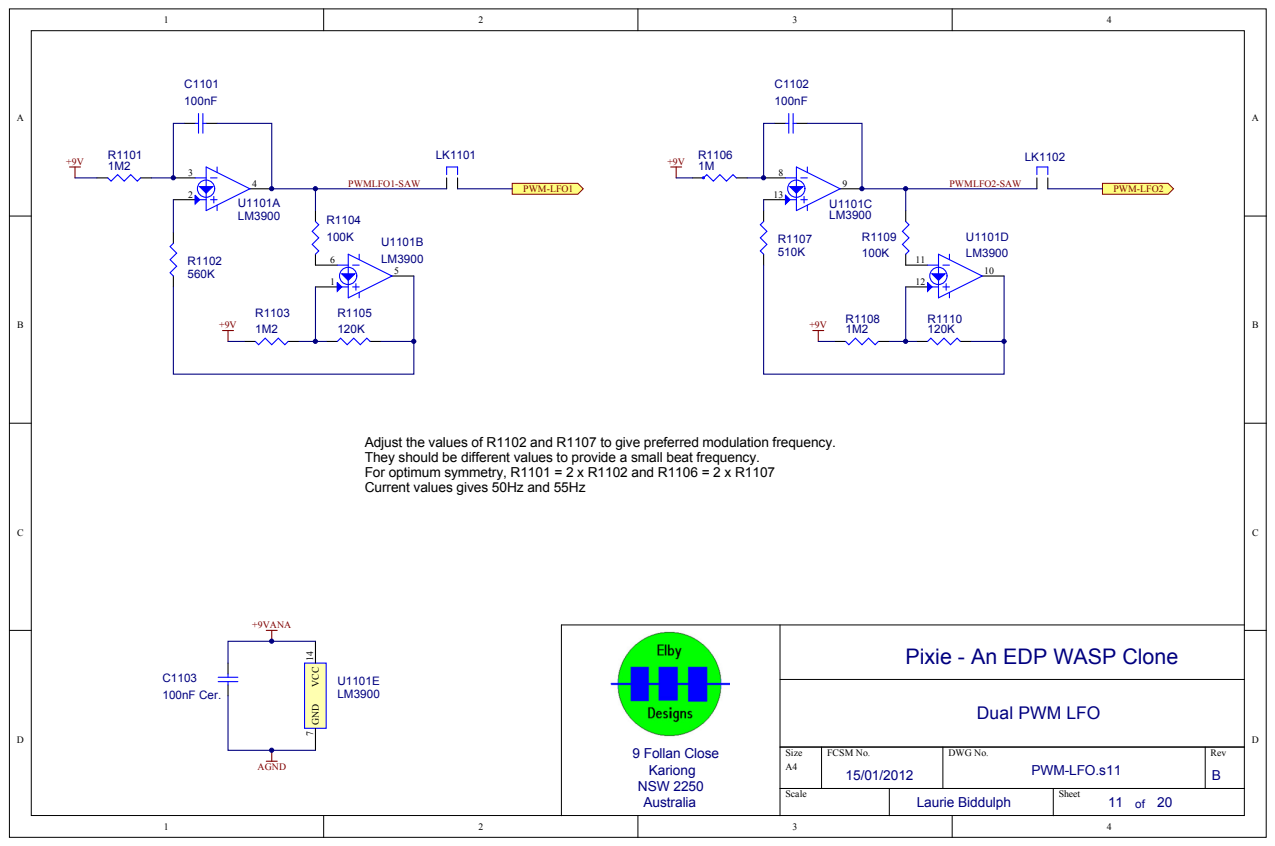
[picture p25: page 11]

Adjust the values of R1102 and R1107 to give preferred modulation frequency.
They should be different values to provide a small beat frequency.
For optimum symmetry, R1101 = 2 x R1102 and R1106 = 2 x R1107
Current values gives 50Hz and 55Hz

Pixie - An EDP WASP Clone

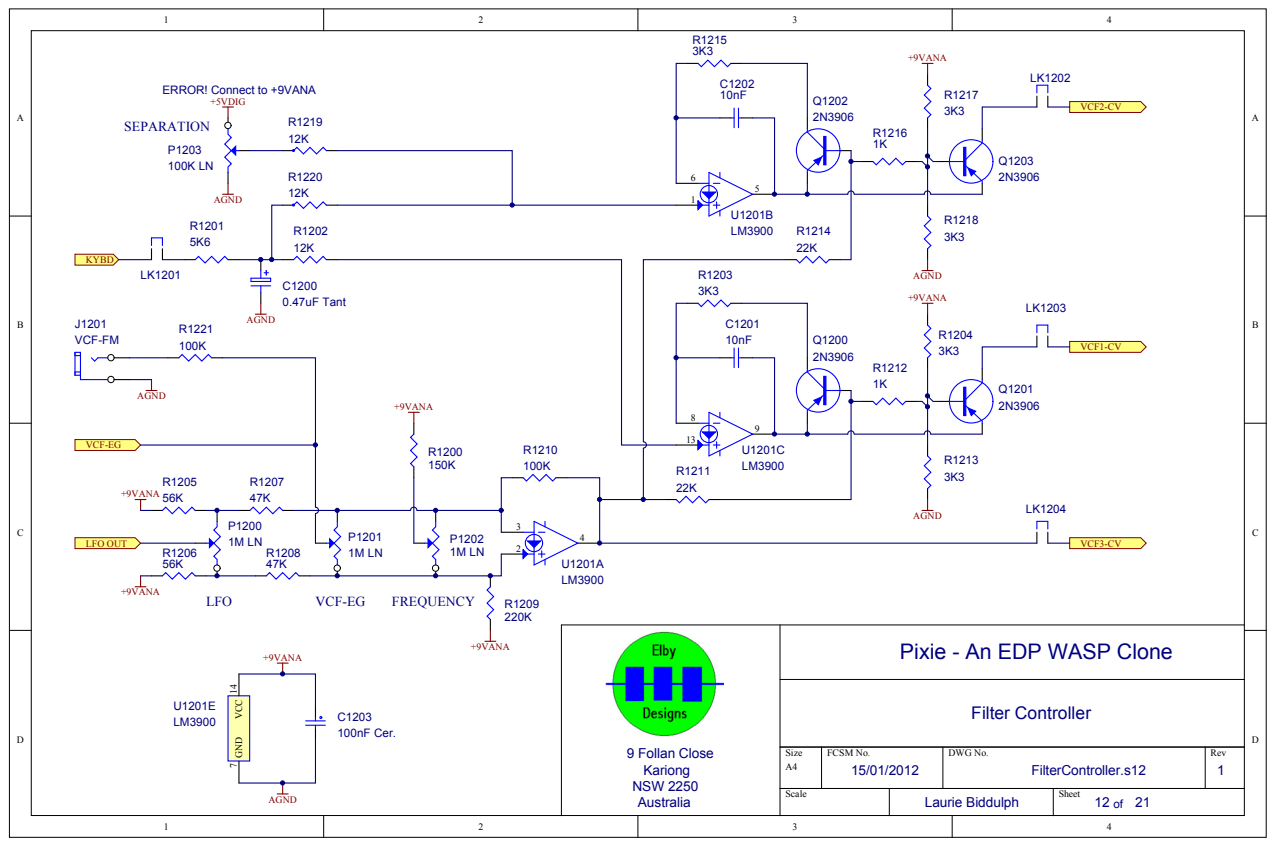
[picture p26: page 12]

Pixie - An EDP WASP Clone


Pixie - An EDP WASP Clone


See
R1-R4, Q1 & Q2 are not on pc

Pixie - an EDP WASP Clone

MIDI Interface and Dual DCO


Pixie - An EDP WASP Clone


Pixie - An EDP WASP Clone


Pixie - An EDP WASP Clone


Taken from a design by Scott Gravenhorst

U251C | | U251E
4069 4069 4069

Pixie - An EDP WASP Clone


AGND | 4069

Distortion circuits courtesy of J. Haible

In mode 5 both VCF1 and VCF2 are in parallel.
In the other modes the output of VCF1 feeds in to VCF2

Pixie - An EDP WASP Clone


Taken from the KORG MS20 Ring Modulator

Pixie - An EDP WASP Clone



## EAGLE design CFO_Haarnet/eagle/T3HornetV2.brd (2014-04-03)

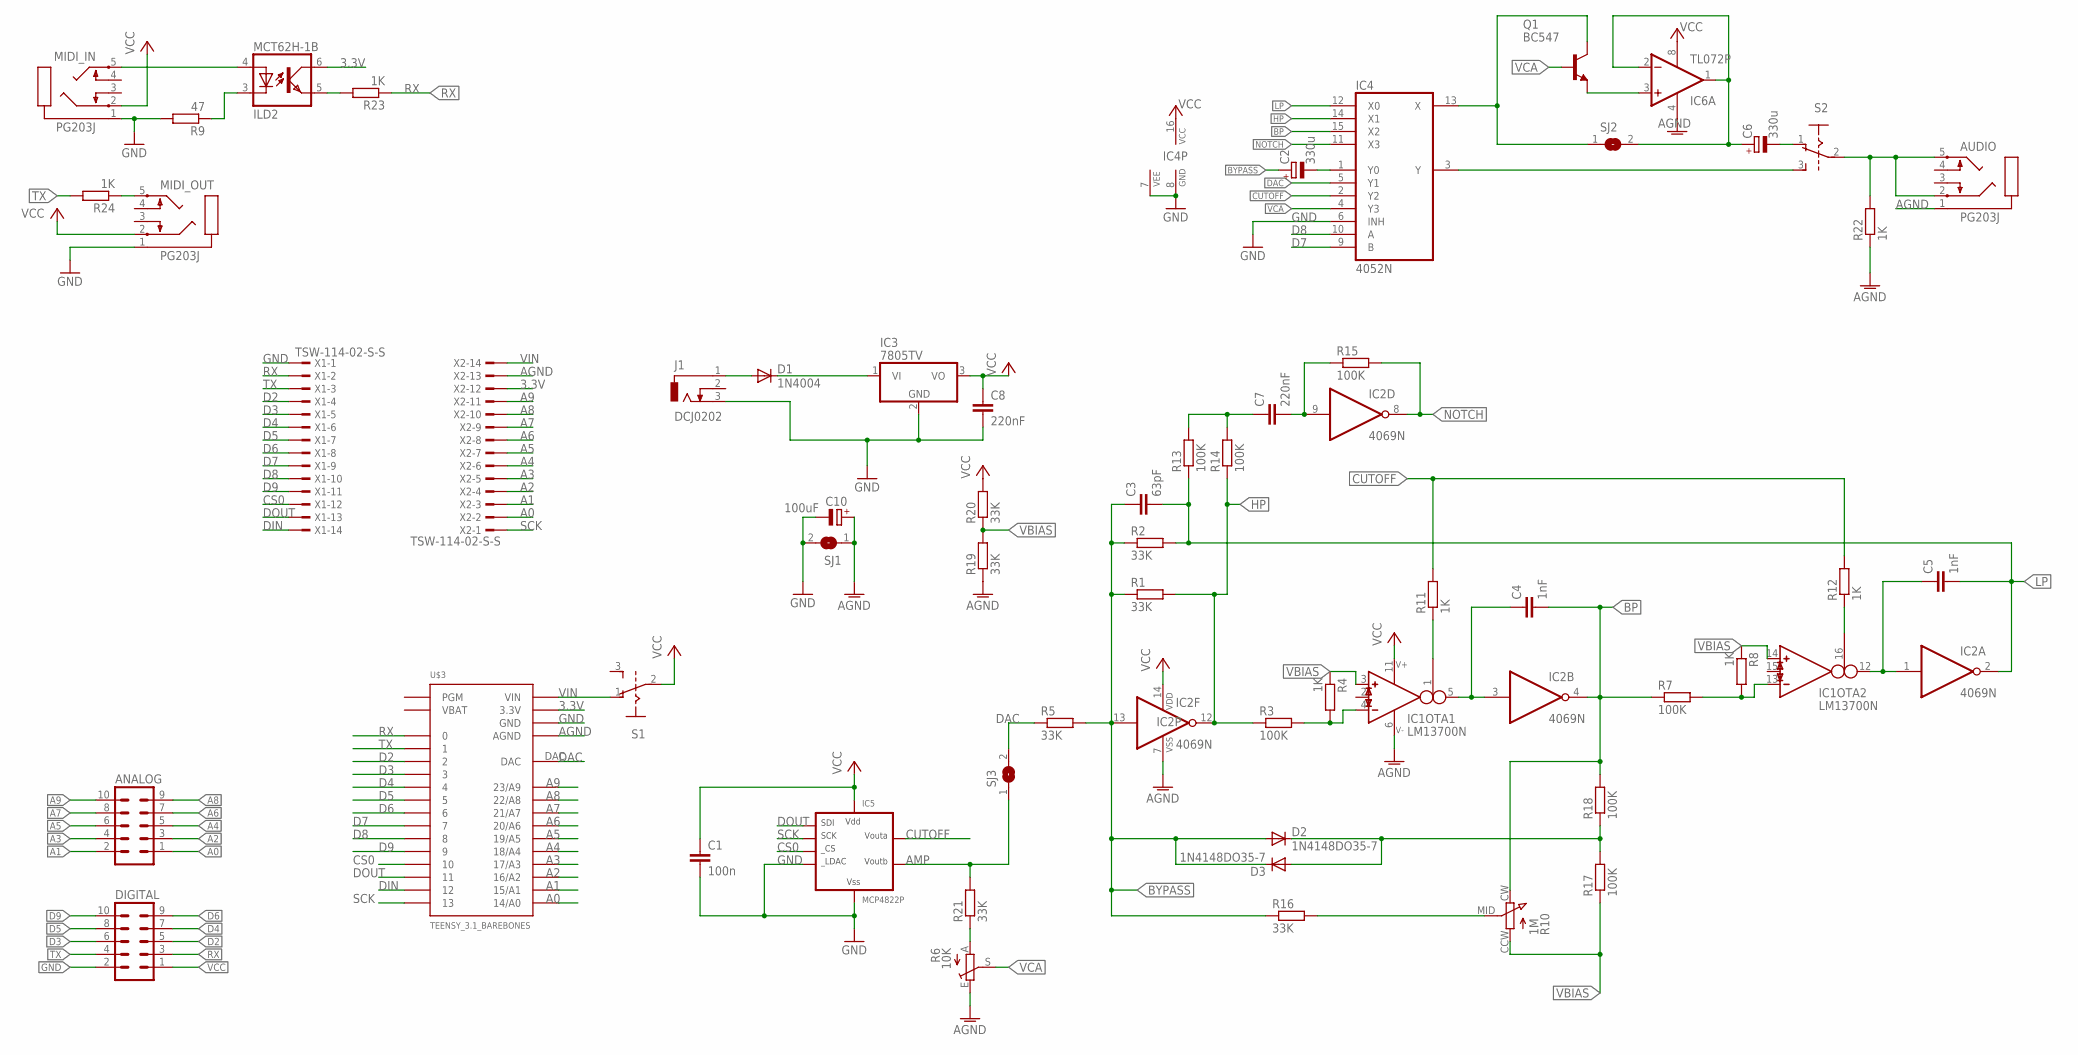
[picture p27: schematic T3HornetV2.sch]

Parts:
ANALOG: ML10
AUDIO: PG203J
C1: 100n; C050-030X075
C2, C6: 330u; E2,5-7
C3: 63pF; C025-024X044
C4, C5: 1nF; C025-024X044
C7, C8: 220nF; C050-030X075
C10: 100uF; E2,5-6
D1: 1N4004; DO41-10
D2, D3: 1N4148DO35-7; DO35-7
DIGITAL: ML10
IC1: LM13700N; DIL16
IC2: 4069N; DIL14
IC3: 7805TV; TO220V
IC4: 4052N; DIL16
IC5: MCP4822P; DIL8
IC6: TL072P; DIL08
J1: DCJ0202
MCT62H-1: ILD2; DIL08
MIDI_IN: PG203J
MIDI_OUT: PG203J
Q1: BC547; TO92
R1, R2, R5, R16, R19, R20, R21: 33K; 0207/7
R3, R7, R13, R14, R15, R17, R18: 100K; 0207/7
R4, R8, R11, R12, R22, R23, R24: 1K; 0207/7
R6: 10K; CA9V
R9: 47; 0207/7
R10: 1M; P120PK
S1, S2: EG1218; GF-126-0159
SJ1, SJ2, SJ3: SJ
U$3: TEENSY_3.1_BAREBONES
X1, X2: TSW-114-02-S-S

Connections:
3.3V: MCT62H-1.6 (COL), U$3.3.3V1 (3.3V), U$3.3.3V2 (3.3V), X2.12
A0: ANALOG.1, U$3.14/A0, X2.2
A1: ANALOG.2, U$3.15/A1, X2.3
A2: ANALOG.3, U$3.16/A2, X2.4
A3: ANALOG.4, U$3.17/A3, X2.5
A4: ANALOG.5, U$3.18/A4, X2.6
A5: ANALOG.6, U$3.19/A5, X2.7
A6: ANALOG.7, U$3.20/A6, X2.8
A7: ANALOG.8, U$3.21/A7, X2.9
A8: ANALOG.9, U$3.22/A8, X2.10
A9: ANALOG.10, U$3.23/A9, X2.11
AGND: AUDIO.1, C10.+, IC1.6 (V-), IC2.7 (VSS), IC6.4 (V-), R6.E, R19.1, R22.1, SJ1.1, U$3.AGND, X2.13
AMP: IC5.6 (VOUTB), R21.2, SJ3.1
BP: C4.2, IC2.4 (O), IC4.15 (X2), R7.1, R10.CW, R18.2
BYPASS: C2.+, C3.1, D2.A, D3.C, IC2.13 (I), R1.1, R2.1, R5.2, R16.1
CS0: IC5.2 (CS), U$3.10, X1.12
CUTOFF: IC4.2 (Y2), IC5.8 (VOUTA), R11.2, R12.2
D2: DIGITAL.5, U$3.2, X1.4
D3: DIGITAL.6, U$3.3, X1.5
D4: DIGITAL.7, U$3.4, X1.6
D5: DIGITAL.8, U$3.5, X1.7
D6: DIGITAL.9, U$3.6, X1.8
D7: IC4.9 (B), U$3.7, X1.9
D8: IC4.10 (A), U$3.8, X1.10
D9: DIGITAL.10, U$3.9, X1.11
DAC: IC4.5 (Y1), R5.1, SJ3.2, U$3.DAC
DIN: U$3.12, X1.14
DOUT: IC5.4 (SDI), U$3.11, X1.13
GND: C1.2, C8.2, C10.-, DIGITAL.2, IC3.2 (GND), IC4.6 (INH), IC4.7 (VEE), IC4.8 (GND), IC5.5 (LDAC), IC5.7 (VSS), J1.3, MIDI_IN.1, MIDI_OUT.1, R9.2, SJ1.2, U$3.GND1 (GND), U$3.GND2 (GND), X1.1
HP: IC2.12 (O), IC4.14 (X1), R1.2, R3.1, R14.1
LP: C3.2, C5.2, IC2.2 (O), IC4.12 (X0), R2.2, R13.1
unnamed: D1.A, J1.1
unnamed: IC6.3 (+IN), Q1.1 (E)
unnamed: D2.C, D3.A, R17.2, R18.1
unnamed: R6.A, R21.1
unnamed: IC1.4 (IN_N), R3.2, R4.2
unnamed: C6.-, S2.1
unnamed: C4.1, IC1.5 (OUT), IC2.3 (I)
unnamed: R10.MID, R16.2
unnamed: IC1.13 (IN_N), R7.2, R8.2
unnamed: IC4.3 (Y), S2.3
unnamed: C5.1, IC1.12 (OUT), IC2.1 (I)
unnamed: C7.2, IC2.9 (I), R15.1
unnamed: IC1.1 (I_BIAS), R11.1
unnamed: IC1.16 (I_BIAS), R12.1
unnamed: C7.1, R13.2, R14.2
unnamed: D1.C, IC3.1 (VI)
unnamed: C6.+, IC6.1 (OUT), IC6.2 (-IN), SJ2.2
unnamed: C2.-, IC4.1 (Y0)
unnamed: AUDIO.2, AUDIO.5, R22.2, S2.2
unnamed: IC4.13 (X), Q1.3 (C), SJ2.1
unnamed: MCT62H-1.5 (EMIT), R23.2
unnamed: MIDI_OUT.5, R24.1
unnamed: MCT62H-1.4 (A), MIDI_IN.5
unnamed: MCT62H-1.3 (C), R9.1
NOTCH: IC2.8 (O), IC4.11 (X3), R15.2
RX: DIGITAL.3, R23.1, U$3.0, X1.2
SCK: IC5.3 (SCK), U$3.13, X2.1
TX: DIGITAL.4, R24.2, U$3.1, X1.3
VBAT: U$3.VBAT
VBIAS: IC1.3 (IN_P), IC1.14 (IN_P), R4.1, R8.1, R10.CCW, R17.1, R19.2, R20.1
VCA: IC4.4 (Y3), Q1.2 (B), R6.S
VCC: C1.1, C8.1, DIGITAL.1, IC1.11 (V+), IC2.14 (VDD), IC3.3 (VO), IC4.16 (VCC), IC5.1 (VDD), IC6.8 (V+), MIDI_IN.2, MIDI_OUT.2, R20.2, S1.2
VIN: S1.1, U$3.VIN, X2.14

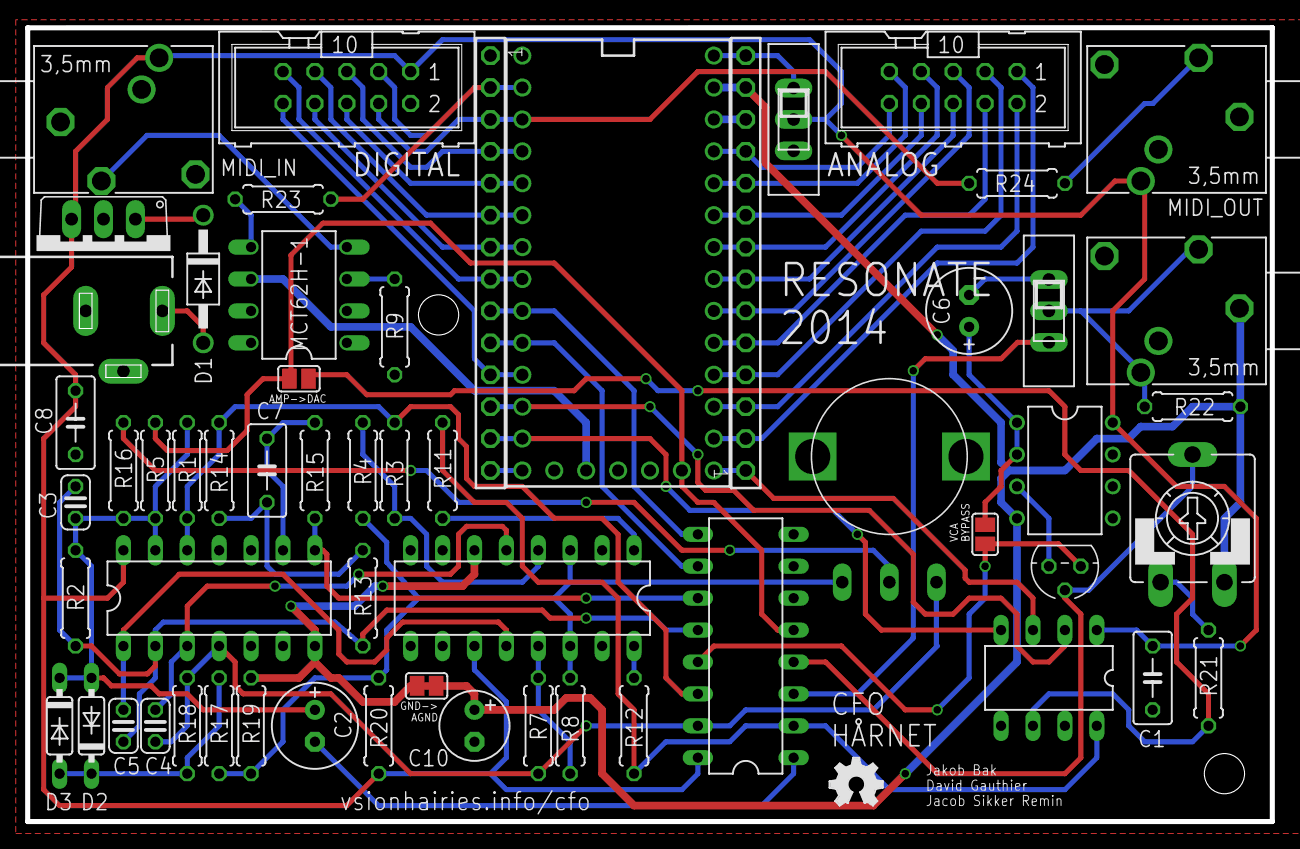
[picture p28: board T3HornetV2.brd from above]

Board: 4 copper layers, 99.1 x 63.2 mm, 59 parts (0 on the bottom side), 63 nets.

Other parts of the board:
U$1: OSHW_FILLX150_NOTEXT

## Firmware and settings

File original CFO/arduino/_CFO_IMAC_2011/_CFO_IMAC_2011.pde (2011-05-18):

//          _             _       _    _            _                   _                  _          _                 _                       _            _          _            _          
//        /\ \           / /\    / /\ /\ \         / /\                /\ \               /\ \       / /\              /\ \         _          /\ \         /\ \       /\ \         /\ \     _  
//       /  \ \         / / /   / / //  \ \       / /  \              /  \ \             /  \ \     / /  \             \_\ \       /\ \       /  \ \       /  \ \     /  \ \       /  \ \   /\_\
//      / /\ \ \       / /_/   / / // /\ \ \     / / /\ \            / /\ \ \           / /\ \ \   / / /\ \            /\__ \   ___\ \_\     / /\ \ \     / /\ \ \   / /\ \ \     / /\ \ \_/ / /
//     / / /\ \ \     / /\ \__/ / // / /\ \_\   / / /\ \ \          / / /\ \_\         / / /\ \_\ / / /\ \ \          / /_ \ \ /___/\/_/_   / / /\ \ \   / / /\ \_\ / / /\ \_\   / / /\ \___/ / 
//    / / /  \ \_\   / /\ \___\/ // /_/_ \/_/  / / /  \ \ \        / / /_/ / /        / /_/_ \/_// / /  \ \ \        / / /\ \ \\__ \/___/\ / / /  \ \_\ / / /_/ / // /_/_ \/_/  / / /  \/____/  
//   / / /    \/_/  / / /\/___/ // /____/\    / / /___/ /\ \      / / /__\/ / _      / /____/\  / / /___/ /\ \      / / /  \/_/  /\/____\// / /   / / // / /__\/ // /____/\    / / /    / / /   
//  / / /          / / /   / / // /\____\/   / / /_____/ /\ \    / / /_____//\_\    / /\____\/ / / /_____/ /\ \    / / /         \ \_\   / / /   / / // / /_____// /\____\/   / / /    / / /    
// / / /________  / / /   / / // / /______  / /_________/\ \ \  / / /       \/ /\  / / /      / /_________/\ \ \  / / /           \/_/  / / /___/ / // / /      / / /______  / / /    / / /     
/// / /_________\/ / /   / / // / /_______\/ / /_       __\ \_\/ / /        /_/ / / / /      / / /_       __\ \_\/_/ /                 / / /____\/ // / /      / / /_______\/ / /    / / /      
//\/____________/\/_/    \/_/ \/__________/\_\___\     /____/_/\/_/         \_\/  \/_/       \_\___\     /____/_/\_\/                  \/_________/ \/_/       \/__________/\/_/     \/_/       
//         

//   ++++++++++++++++++++++++++++++++++++++++++++++++++++++++++++++++++++++++++++++++
//   + CHEAP, FAT and OPEN                                                          +
//   + an open source platform for musical exploration, composition and performance +
//   + by jacob sikker remin                                                        +
//   + re:new / IMAC 2011 - the unheard avantgarde revision - may 2011              +
//   + project home: http://8bitklubben.dk/project/CFO/                             +
//   ++++++++++++++++++++++++++++++++++++++++++++++++++++++++++++++++++++++++++++++++

// sound processing based on the arduino pocket piano code and circuit, by critter and guittari
// more info: http://www.critterandguitari.com/home/store/arduino-piano.php

// GENERAL OPTIMIZATION NOTE
// labelled code where i see abvious places for optimization
// OPTIMIZE (code works, but messy), TO CHECK (something might be up here), NEW THING (new feature, nice to have), SETTING (add this variable to settings menu)

// TODO
// stylophone octave is taken over by sequencer / memory sequence
// these should be seperated, so that one can still jam with the sequence in the expected octave
// IDEAS
// timing issues: 
// gate sequencer should be able to sync with processing + have its own time
// substeps
// memory sequencer: UP / DOWN could double / half the memory sequence length

#include <stdio.h>                      // lets us do some C string manipulations for the LCD display
#include <avr/pgmspace.h>               // lets us use progmem for the giant wavetables
#include <LiquidCrystal.h>              // LCD display library
#include <EEPROM.h>                     // lets us read from and write to the EEPROM

// LCD setup
LiquidCrystal lcd(16, 17, 3, 5, 6, 7);  // LiquidCrystal(rs, enable, d4, d5, d6, d7) 
char printMsg[17];                      // 16 chars plus end line char
char oldPrintMsg1[17];                  // i guess this could be a two dimensional array... OPTIMIZE?
char oldPrintMsg2[17];
int delayLCD = 100;
unsigned long lastLCDUpdate = millis();

// rotary encoder
#define encoder0PinA  2 
#define encoder0PinB  12
volatile unsigned int encoder0Pos = 0;
unsigned int oldEncoder0Pos = encoder0Pos;
int encoderChange = 0;

// sound generation
int frequency = 0;
byte gain = 0xff;                       // gain of oscillator
byte waveForm = 0;
byte modulatorWaveForm = 0;
char* waveName[] = {"sine","square","pulse","triangle","sawtooth","fuzzsquare","digiwave 1","digiwave 2","digiwave 3","digiwave 4","digiwave 5","digiwave 6",
  "tanwave 1","tanwave 2","tanwave 3","tanwave 4"};
#define numberOfWaveforms 16
// FM synthesis // research should go in to this! OPTIMIZE // NEW THING
uint16_t harmonicity = 0;              // harmonicity (first 8 bits are fractional)
uint8_t modulatorDepth = 0;            // modulation depth (0 - 255)

// define keynames, and which octave they belong to
char* noteNames[] = {"A ", "A#", "B ", "C ", "C#", "D ", "D#", "E ", "F ", "F#", "G ", "G#", "A ", "A#", "H ", "C ", "C#", "D ", "D#", "E "};
int octaveAdd[20] = {-1,-1,-1,0,0,0,0,0,0,0,0,0,0,0,0,1,1,1,1,1};
// hertz values for each stylophone key
int hertzTable[20] = {370,392,415,440,466,494,523,555,587,622,659,699,740,784,831,880,932,988,1047,1109};
int octave = 0;                       //current base octave
//int sequencerOctave = 0;              //current octave of sequencer

//button input, through resistor ladder connected to analog input 0
int buttonVal[6] = {161, 325, 492, 662, 838, 1023};
#define MODE 0
#define DOWN 1
#define LEFT 2
#define RIGHT 3
#define OK 4
#define UP 5
int buttonNoise = 25;                 //is suddenly superhigh? TO CHECK!
int activeButton = -1;                
int oldActiveButton = activeButton;
boolean buttonPushed = false;         //this could be redundant if -1 was used for non-active. OPTIMIZE

//stylophone input, through resistor ladder connected to analog input 5
unsigned int styloVal[20] PROGMEM = {53, 101, 148, 193, 238, 282, 327, 372, 417, 462, 509, 557, 606, 657, 710, 765, 824, 886, 952, 1022};
int styloNoise = 25;                  //noise threshold on analog input pin, might be different on non-fixed PCBs. TO CHECK
int activeKey = -1;
int oldActiveKey = activeKey;
boolean styloMapping = true;

// setup up shift register
int latchPin = 8;
int clockPin = 4;
int dataPin = 15;
// a byte keeps 8 bits
byte data1 = 0;
byte data2 = 0;
// (NOTE: an int keeps 16, so we should be able to keep all info in one int. OPTIMIZE)
// bools to keep LED status. this is redundant as we keep the info in data1/2 already. OPTIMIZE.
boolean LED[16] = {true, true, true, true, true, true, true, true, true, true, true, true, true, true, true, true};
//#define LEDFrequency = 200 //update LEDs ever 200 milliseconds, or 50 times a second --- are LEDs updated every cycle now? TO CHECK

//general navigation and logic
long lastLEDUpdate = millis();
int mode = 0;
int oldMode = mode;
#define numberOfModes 4
char* modeName[] = {"stylophone", "modulation", "sequencer", "settings"};
int pitchBend;
#define STYLOPHONE 0
#define MODULATION 1
#define SEQUENCER 2
#define SETTINGS 3

//char* settingsName[] = {"decay", "master", "slave"}; lets make it stupid stupid
int activeSetting = 0;

//analog inputs
#define BUTTONS 0
#define STYLOPHONE_INPUT 5
#define EXPRESSION 4

//gate sequencer
int counter = 0;
int tempo = 100;                       //should be BPM, right now it is just a delay. OPTIMIZE
unsigned long lastBeat = millis();
boolean gate[16] = {true, true, true, true, true, true, true, true, true, true, true, true, true, true, true, true}; //same as LED? redundant. OPTIMIZE
boolean sequenceBlink = false;
boolean editing = false;
#define LEDBlink 50                    //length of each sequencer blink

unsigned long lastKeyPress = millis();
#define waitForKeypress 50             //pause for each keypress

#define notTouched 60000               //go to instructions mode if not touched for X ms
boolean instructionsMode = false;      
unsigned long lastUse = millis();
char* instructionText[] = {"hello", "how to play:", "connect cable", "to piano keys", "use push keys", "and knob", "to edit sound", "and sequencer", "enjoy!"};
#define instructionsSpeed 2000         //each instruction on screen for X ms
int instruction = 0;
int oldInstruction = -1;
int numberOfInstructions = 9;          //this could be checked automatically. OPTIMIZE.
boolean demoProne = true;              //set to true for demo mode when inactive

//sequencer
int bpm = 160;
boolean looping = false;

int memNoteStart = 0, memNoteEnd = 3, memNoteSubsteps = 4, memNotePos = 0, memCommandStart = 0, memCommandEnd = 3, memCommandSubsteps = 4, memCommandPos = 0;
int sequenceStart = 0, sequencePosition = sequenceStart, sequenceLength = 16, sequenceSubsteps = 4;

unsigned long lastNote, lastCommand;
unsigned long lastSequenceStep = millis();
int millisPerNote, millisPerCommand;
int delayPerBeat = 100;

int lastNoteSent, lastOctave, lastCommandSent, lastCommandValue; // could be bytes? OPTIMZE
int memNoteLoops, memCommandLoops;

int millisPerSequenceStep = 60000/bpm/4;

boolean master = true, slave = false;

//music table: 4 bytes/step: NOTE, OCTAVE, COMMAND, COMMAND VALUE
prog_uchar musicTable[] PROGMEM = {
0,1,255,255,255,255,255,255,255,255,255,255,255,255,255,255,4,255,255,255,7,255,255,255,255,255,255,255,0,2,255,255,0,0,255,255,255,255,215,1,255,255,255,255,255,255,255,255,9,255,215,0,0,255,255,255,255,255,255,255,255,255,255,255,
7,3,215,12,7,1,215,3,0,2,215,11,7,3,215,3,0,1,215,12,0,2,215,3,10,2,215,13,0,1,215,3,0,1,215,12,10,2,215,3,0,1,215,11,0,1,215,3,5,1,215,13,0,1,215,3,0,2,215,12,5,1,215,3,8,1,215,11,0,2,215,3,5,2,215,11,8,1,215,3,7,1,215,13,5,2,215,3,10,2,215,12,7,1,215,3,5,2,215,12,10,2,215,3,3,2,215,13,5,2,215,3,10,2,215,12,3,2,215,3,7,1,215,13,10,2,215,3,
7,4,215,11,7,1,215,3,0,2,215,255,7,4,215,3,0,1,215,11,0,2,215,3,10,2,215,255,0,1,215,3,0,1,215,2,10,2,215,3,0,1,215,4,0,1,215,3,5,3,215,6,0,1,215,3,0,2,215,7,5,3,215,3,8,1,215,9,0,2,215,3,5,1,215,8,8,1,215,3,7,1,215,7,5,1,215,3,10,2,215,9,7,1,215,3,5,4,215,6,10,2,215,3,3,2,215,9,5,4,215,3,9,2,215,8,3,2,215,3,7,1,215,6,9,2,215,3,
7,1,215,12,8,4,215,3,0,3,215,11,7,1,215,3,3,2,215,12,0,3,215,3,5,1,215,13,3,2,215,3,7,2,215,1,5,1,215,3,7,2,215,11,7,2,215,3,5,1,215,5,7,2,215,3,8,1,215,12,5,1,215,3,0,2,215,11,8,1,215,3,0,2,215,8,0,2,215,3,10,1,215,13,0,2,215,3,0,1,215,9,10,1,215,3,0,1,215,10,0,1,215,3,3,1,215,11,0,1,215,3,0,1,215,15,3,1,215,3,8,4,215,4,0,1,215,3,
7,1,215,12,8,4,215,3,0,3,215,8,7,1,215,3,3,4,215,8,0,3,215,3,5,1,215,13,3,4,215,3,7,2,215,1,5,1,215,3,2,4,215,11,7,2,215,3,5,1,215,5,2,4,215,3,8,1,215,12,5,1,215,3,0,2,215,11,8,1,215,3,0,2,215,8,0,2,215,3,10,3,215,7,2,4,215,7,0,1,215,9,2,4,215,3,0,4,215,10,0,1,215,3,3,1,215,11,0,4,215,3,0,1,215,15,3,1,215,3,8,4,215,4,0,1,215,3,
7,3,215,12,7,1,215,3,10,3,215,11,7,3,215,3,0,1,215,12,10,3,215,3,10,2,215,13,0,1,215,3,3,1,215,1,10,2,215,3,0,1,215,11,2,1,215,3,5,1,215,5,0,1,215,3,0,2,215,12,5,1,215,3,10,1,215,11,0,2,215,3,5,2,215,8,10,1,215,3,3,1,215,13,5,2,215,3,8,2,215,9,3,1,215,3,5,2,215,10,7,2,215,3,7,3,215,11,5,2,215,3,10,2,215,15,7,3,215,3,7,1,215,11,10,2,215,3,
9,1,215,1,0,2,215,2,255,255,255,255,0,0,215,9,255,255,255,255,3,255,255,255,4,255,194,100,255,255,255,255,9,255,255,255,255,255,255,255,0,0,215,1,255,255,255,255,1,255,194,20,255,255,255,255,255,255,255,255,255,255,255,255,  
0,0,199,255,4,0,215,0,255,255,215,0,255,255,215,0,2,255,215,3,9,255,215,9,2,1,215,9,9,255,255,255,9,1,199,255,4,255,255,255,5,0,199,255,9,255,199,200,11,1,199,255,9,255,215,4,9,255,203,255,9,255,207,63,
2,0,207,62,4,1,199,255,0,0,203,255,0,1,199,255,0,0,203,255,5,1,199,255,0,0,203,255,0,0,255,255,0,1,199,10,0,0,231,114,0,1,231,114,0,0,231,114,0,1,231,114,0,0,231,14,0,1,231,14,0,0,231,14,
0,3,194,10,0,4,255,255,0,3,255,255,0,4,255,255,0,3,194,20,0,4,255,255,0,3,255,255,0,4,255,255,0,3,194,40,0,4,255,255,0,3,255,255,0,4,255,255,0,3,194,80,0,4,255,255,0,3,255,255,0,4,255,255,
0,4,194,255,0,3,194,255,0,4,215,3,0,3,199,255,0,4,255,255,0,3,255,255,0,4,255,255,0,3,255,255,0,4,255,255,0,3,255,255,0,4,255,255,0,3,255,255,0,4,255,255,0,3,255,255,0,4,194,1,0,3,255,255,  
0,0,194,100,0,2,255,255,0,0,255,255,0,2,255,255,0,0,194,10,0,2,255,255,0,0,255,255,0,2,255,255,0,0,194,255,0,2,255,255,0,0,255,255,0,2,255,255,0,0,194,1,0,2,255,255,0,0,255,255,0,2,255,255,
2,0,207,64,4,1,199,255,0,0,203,255,0,1,199,255,0,0,203,255,5,1,199,255,0,0,203,255,0,0,255,255,0,1,199,10,0,0,231,114,0,1,231,114,0,0,231,114,0,1,231,114,0,0,231,14,0,1,231,14,0,0,231,14 //elevatormusik, 16steps
};

int musicTableLength = 512; // should be automated. TO CHECK / FIX

byte ID = 0;                // ID of this specific unit

unsigned long killTime; // added to be able to kill notes -- not working very well -- OPTIMIZE
boolean kill = false;

//tracker idle
unsigned long idle = millis();
#define idletime 800
boolean isIdle = false;

//setup decay
int sustain = 100; //in ms
byte decaySteps = 10, decaySpeed = 50, endDecay = 0;
boolean decaying = false;
unsigned long lastDecay = millis();
byte startAttack = 255, endAttack = 255, attackSteps = 50, attackSpeed = 1;
boolean attacking = true;
unsigned long lastAttack = millis();

boolean gateOn = true;

unsigned long lastSequenceEdit = millis();
#define sequenceEditTime 50

boolean takeStep = false;
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
void loop() { // IN GENERAL: loop() has too much code in it! OPTIMIZE
  //read expression control
  int expressionRead = analogRead(EXPRESSION);
  pitchBend = expressionRead * 2;      // multiplication amount should be tweakable. SETTING.
  //check for keypresses
  if (millis() > lastKeyPress+waitForKeypress) readButtons();
  //read stylophone input  
  int styloRead = analogRead(STYLOPHONE_INPUT);

  // attack / sustain / release hack
  

  if (attacking && (millis() > lastAttack + attackSpeed)) {
//    sprintf(printMsg, "attacking: %3d", gain);
//    printLCD(printMsg,1);  
    lastAttack = millis();
    if (gain < (endAttack-attackSteps)) {
      gain = gain + attackSteps;
    } else {
      gain = endAttack;
      attacking = false;
      //decaying = true;
    }
    //sprintf(printMsg, "gain: %3d", gain);
    //printLCD(printMsg,1);  
  }
  
  // start decay when sustain is over
  if (millis() > lastNote + sustain && styloRead < styloNoise) {
    decaying = true;
  }
  
  if (decaying && (millis() > lastDecay + decaySpeed)) {
//    sprintf(printMsg, "decaying: %3d", gain);
//    printLCD(printMsg,1); 
    lastDecay = millis();
    if (gain > (endDecay+decaySteps)) {
      gain = gain - decaySteps;
    } else {
      gain = endDecay;
      decaying = false;
    }
    //sprintf(printMsg, "gain: %3d", gain);
    //printLCD(printMsg,1);  
  }

  
  if (instructionsMode && demoProne) {
    displayInstructions();
  } else {  
    //the code above in loop() should not be needed. except reading the inputs. OPTIMIZE.
    switch (mode) {
      case STYLOPHONE:
        //stylophone / gate sequencer edit mode
        checkEncoder();
        if (encoderChange != 0) {
          tempo += encoderChange*5;
          sprintf(printMsg, "delay: %3d", tempo);
          printLCD(printMsg,0);     
          instructionsMode = false;
        }
        
        gateSequencerKeyCheck();     // check for keypresses

        if (editing) {
          gateSequencerInput();      // edit gate sequencer, this is super unprecise. OPTIMIZE.
        } else {
          stylophoneInput();         // jam that stylophone!
        }
        break;
      
      case MODULATION:
        //modulator mode
        modulationKeyCheck();
        stylophoneInput();
        break;

      case SEQUENCER:
        //sequencer mode
        sequencerKeyCheck();
        stylophoneInput();
        break;
        
      case SETTINGS:
        //tweak them settings
        switch(activeSetting) {
          case 0: // change attack steps
            checkEncoder();
            attackSteps += encoderChange;
            attackSteps = constrain (attackSteps, 0, 255);
            sprintf(printMsg, "attackSteps: %3d", attackSteps);
            printLCD(printMsg,1);
            break;
          case 1: // attack speed
            checkEncoder();
            attackSpeed += encoderChange;
            attackSpeed = constrain (attackSpeed, 0, 255);
            sprintf(printMsg, "attackSpeed: %3d", attackSpeed);
            printLCD(printMsg,1);
            break;
          case 2: // attack speed
            checkEncoder();
            sustain += encoderChange*5;
            sustain = max(sustain, 0);
            sprintf(printMsg, "sustain(ms):%4d", sustain);
            printLCD(printMsg,1);
            break;
          case 3: // change decay steps
            checkEncoder();
            decaySteps += encoderChange;
            decaySteps = constrain (decaySteps, 0, 255);
            sprintf(printMsg, "decaySteps: %3d", decaySteps);
            printLCD(printMsg,1);
            break;
          case 4: // decay speed
            checkEncoder();
            decaySpeed += encoderChange;
            decaySpeed = constrain (decaySpeed, 0, 255);
            sprintf(printMsg, "decaySpeed: %3d", decaySpeed);
            printLCD(printMsg,1);
            break;
          case 5: // decay speed
            checkEncoder();
            startAttack += encoderChange;
            startAttack = constrain (startAttack, 0, 255);
            sprintf(printMsg, "attack gain: %3d", startAttack);
            printLCD(printMsg,1);
            break;
          case 6: // decay speed
            checkEncoder();
            endDecay += encoderChange;
            endDecay = constrain (endDecay, 0, 255);
            sprintf(printMsg, "end gain: %3d", endDecay);
            printLCD(printMsg,1);
            break;            
          case 7: // master/slave setting
            checkEncoder();          
            if (encoderChange == 1) { 
              master = true;       
              slave = false;
            }
            if (encoderChange == -1) {
              slave = true;
              master = false;
            }
            if (master) {
              printLCD("sync: master", 1);
            } else {
              printLCD("sync: slave", 1);
            }
            break;
          
        }
        settingsKeyCheck();
        stylophoneInput();
        break;
    }    
    
  }

  updateGateSequencer();
  checkModeChange();
  
  if (looping) sequencer();
  
  if (Serial.available() >= 6) parseSerial();
  if (slave && Serial.available()) serialReadIR();

  if (!instructionsMode && millis() > lastUse + notTouched) {
    instructionsMode = true;
    instruction = 0;
  }
  
  //allow super short notes with kill command
//  if (kill && (killTime < millis())) {
//    gain = 0;
//    kill = false;
//    printLCD("argh!",0);
//  }
}

void startupAnim() {
  //bling bling
  lcd.begin(16,2);
  
  createCharacters();
  
  lcd.setCursor(13, 0);
  lcd.write(0);
  lcd.setCursor(13, 1);
  lcd.write(1);
  lcd.setCursor(14, 0);
  lcd.write(2);
  lcd.setCursor(14, 1);
  lcd.write(3);
  lcd.setCursor(15, 0);
  lcd.write(4);
  lcd.setCursor(15, 1);
  lcd.write(5);
  
  lcd.setCursor(0,0);
  lcd.print("CHEAP,FAT");
  lcd.setCursor(0,1);
  lcd.print("and OPEN");
  
  delay(1000);
  lcd.clear();
  lcd.setCursor(0,1);
  lcd.print("let's go!");
}

void serialReadIR() {
  char val = Serial.read();
  
//  sprintf(printMsg, "incoming IR: %1c", val);
//  printLCD(printMsg,1);
  
  if (val == 'R') {
    counter = 0;
    lastBeat = millis();
    sequenceBlink = true; 
  }
  if (val == 'S') {
    counter++;
    counter = counter%16;
    lastBeat = millis();
    sequenceBlink = true;
  } 
}

void settingsKeyCheck() {
  if (buttonPushed) {
    switch (activeButton) {
      case MODE:
        mode++;
        break;
      case DOWN:
        activeSetting++;
        break;
      case UP:
        activeSetting --;
        activeSetting = constrain(activeSetting,0,255); // SET TO MAX NR OF SETTINGS
        break;
        
    }
  }
  buttonPushed = false;
}

void displayInstructions () {
    //instructionsmode
    instruction = (millis() - lastUse) / instructionsSpeed;
    instruction = instruction % numberOfInstructions;
    if (instruction != oldInstruction) {
      printLCD ("CHEAP,FAT+OPEN",0);
      printLCD (instructionText[instruction],1);
      oldInstruction = instruction;
    }
    stylophoneInput();
}

void gateSequencerInput () {                        //read stylophone input, map to stylophone keys and flip corresponding sequencer gate
  
  int styloRead = analogRead(STYLOPHONE_INPUT);
  
  
  
  if (styloRead > styloNoise) {
    lastUse = millis();
    activeKey = stylophoneMapping (styloRead);  // map analog input to stylophone keys
    
    if (activeKey != oldActiveKey) {
      if (millis() > lastSequenceEdit + sequenceEditTime) {
        gate[activeKey] = !gate[activeKey];       // flip sequencer gate
        oldActiveKey = activeKey;
        lastSequenceEdit = millis();
      }
    }
    
  } else {
    activeKey = -1;
  }  
}
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

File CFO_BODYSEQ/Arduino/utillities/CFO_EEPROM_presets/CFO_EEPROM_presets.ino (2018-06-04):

// the quick fix for more interesting user presets on EEPROM

// WARNING: this will erase ALL user presets on CFO!

// 16 presets
// 128 data points in each
byte presetData [] =
/*
{
16, 12, 0, 1, 0, 1, 20, 0, 46, 2, 0, 64, 64, 127, 2, 127, 0, 3, 2, 0, 0, 76, 71, 127, 4, 0, 0, 0, 0, 0, 0, 52, 69, 127, 1, 127, 0, 2, 2, 0, 0, 0, 0, 0, 0, 0, 0, 0, 0, 0, 0, 0, 0, 0, 0, 0, 0, 0, 0, 0, 0, 0, 0, 0, 0, 0, 0, 0, 0, 0, 81, 0, 0, 0, 0, 0, 0, 0, 0, 0, 0, 0, 0, 0, 0, 0, 0, 0, 0, 0, 0, 0, 0, 0, 0, 0, 0, 0, 0, 0, 0, 0, 0, 0, 0, 0, 0, 0, 0, 0, 0, 0, 0, 0, 61, 0, 90, 64, 0, 0, 0, 0, 0, 0, 59, 0, 127, 64, 
16, 8, 0, 0, 0, 1, 48, 0, 46, 0, 0, 64, 64, 127, 1, 127, 0, 2, 2, 0, 0, 76, 66, 127, 4, 0, 0, 0, 0, 0, 0, 52, 64, 127, 1, 127, 0, 2, 2, 0, 0, 0, 0, 0, 0, 0, 0, 0, 0, 0, 0, 0, 0, 0, 0, 0, 0, 0, 0, 0, 0, 0, 0, 0, 0, 0, 0, 0, 0, 0, 84, 0, 2, 0, 0, 0, 0, 0, 0, 0, 0, 0, 0, 0, 0, 0, 0, 0, 0, 0, 0, 0, 0, 0, 0, 0, 0, 0, 0, 0, 0, 0, 0, 0, 0, 0, 0, 0, 0, 0, 0, 0, 0, 0, 12, 64, 127, 64, 0, 0, 0, 0, 0, 0, 0, 46, 127, 64,
16, 9, 0, 0, 0, 1, 48, 0, 46, 0, 0, 64, 64, 127, 2, 127, 0, 2, 2, 0, 0, 76, 66, 127, 4, 0, 0, 0, 0, 0, 0, 52, 64, 127, 1, 127, 0, 2, 2, 0, 0, 0, 0, 0, 0, 0, 0, 0, 0, 0, 0, 0, 0, 0, 0, 0, 0, 0, 0, 0, 0, 0, 0, 0, 0, 0, 0, 0, 0, 0, 84, 0, 2, 0, 0, 0, 0, 0, 0, 0, 0, 0, 0, 0, 0, 0, 0, 0, 0, 0, 0, 0, 0, 0, 0, 0, 0, 0, 0, 0, 0, 0, 0, 0, 0, 0, 0, 0, 0, 0, 0, 0, 0, 0, 12, 64, 127, 64, 0, 0, 0, 0, 0, 0, 0, 46, 127, 64,
16, 13, 0, 0, 0, 1, 127, 0, 46, 0, 0, 64, 64, 127, 2, 127, 0, 2, 2, 0, 0, 76, 66, 127, 4, 32, 0, 1, 0, 0, 0, 52, 64, 127, 1, 127, 0, 2, 2, 0, 0, 0, 0, 0, 0, 0, 0, 0, 0, 0, 0, 0, 0, 0, 0, 0, 0, 0, 0, 0, 0, 0, 0, 0, 0, 0, 0, 0, 0, 0, 84, 0, 2, 0, 0, 0, 0, 0, 0, 0, 0, 0, 0, 0, 0, 0, 0, 0, 0, 0, 0, 0, 0, 0, 0, 0, 0, 0, 0, 0, 0, 0, 0, 0, 0, 0, 0, 0, 0, 0, 0, 0, 0, 0, 12, 64, 127, 64, 0, 0, 0, 0, 0, 0, 0, 46, 127, 64, 
17, 17, 0, 1, 22, 1, 110, 0, 0, 0, 0, 70, 64, 127, 6, 77, 0, 0, 0, 0, 0, 64, 64, 127, 9, 0, 0, 0, 0, 0, 0, 64, 64, 127, 0, 127, 0, 0, 0, 0, 0, 0, 0, 0, 0, 0, 0, 0, 0, 0, 0, 0, 0, 0, 0, 0, 0, 0, 0, 0, 0, 0, 0, 0, 0, 0, 0, 0, 0, 0, 107, 0, 5, 0, 0, 0, 0, 0, 0, 0, 0, 0, 0, 0, 0, 0, 0, 0, 0, 0, 0, 0, 0, 0, 0, 0, 0, 0, 0, 0, 0, 0, 0, 0, 0, 0, 0, 0, 0, 0, 0, 0, 0, 1, 20, 64, 127, 64, 0, 0, 0, 0, 0, 1, 127, 46, 0, 64, 
21, 1, 0, 0, 49, 0, 2, 0, 97, 0, 0, 64, 64, 127, 1, 0, 0, 0, 0, 0, 0, 64, 64, 127, 0, 10, 0, 0, 0, 0, 0, 64, 64, 127, 0, 8, 0, 0, 0, 0, 0, 0, 0, 0, 0, 0, 0, 0, 0, 0, 0, 0, 0, 0, 0, 0, 0, 0, 0, 0, 0, 0, 0, 0, 0, 0, 0, 0, 0, 0, 37, 0, 0, 0, 0, 0, 0, 0, 0, 0, 0, 0, 0, 0, 0, 0, 0, 0, 0, 0, 0, 0, 0, 0, 0, 0, 0, 0, 0, 0, 0, 0, 0, 0, 0, 0, 0, 0, 0, 0, 0, 0, 0, 1, 12, 64, 127, 64, 0, 0, 0, 0, 0, 1, 0, 46, 0, 64, 
22, 1, 0, 0, 49, 0, 2, 0, 97, 0, 0, 64, 64, 127, 1, 0, 0, 0, 0, 0, 0, 64, 64, 127, 0, 10, 0, 0, 0, 0, 0, 64, 64, 127, 0, 8, 0, 0, 0, 0, 0, 0, 0, 0, 0, 0, 0, 0, 0, 0, 0, 0, 0, 0, 0, 0, 0, 0, 0, 0, 0, 0, 0, 0, 0, 0, 0, 0, 0, 0, 37, 0, 0, 0, 0, 0, 0, 0, 0, 0, 0, 0, 0, 0, 0, 0, 0, 0, 0, 0, 0, 0, 0, 0, 0, 0, 0, 0, 0, 0, 0, 0, 0, 0, 0, 0, 0, 0, 0, 0, 0, 0, 0, 1, 12, 64, 127, 64, 0, 0, 0, 0, 0, 1, 0, 46, 0, 64,
19, 19, 0, 0, 0, 1, 0, 0, 0, 0, 0, 64, 64, 127, 1, 0, 0, 0, 0, 0, 0, 64, 64, 127, 0, 0, 0, 0, 0, 0, 0, 64, 64, 127, 0, 0, 0, 0, 0, 0, 0, 0, 0, 0, 0, 0, 0, 0, 0, 0, 0, 0, 0, 0, 0, 0, 0, 0, 0, 0, 0, 0, 0, 0, 0, 0, 0, 0, 0, 0, 126, 0, 2, 0, 0, 0, 0, 0, 0, 0, 0, 0, 0, 0, 0, 0, 0, 0, 0, 0, 0, 0, 0, 0, 0, 0, 0, 0, 0, 0, 0, 0, 0, 0, 0, 0, 0, 0, 0, 0, 0, 0, 0, 1, 12, 64, 127, 64, 0, 0, 0, 0, 0, 1, 0, 46, 0, 64,
22, 5, 0, 0, 20, 0, 34, 0, 0, 0, 0, 64, 59, 71, 1, 127, 0, 3, 1, 0, 0, 64, 68, 127, 0, 94, 0, 0, 2, 0, 123, 64, 64, 127, 0, 83, 0, 0, 1, 0, 0, 0, 0, 0, 0, 0, 0, 0, 0, 0, 0, 0, 0, 0, 0, 0, 0, 0, 0, 0, 0, 0, 0, 0, 0, 0, 0, 0, 0, 0, 17, 0, 2, 0, 0, 0, 0, 0, 0, 0, 0, 0, 0, 0, 0, 0, 0, 0, 0, 0, 0, 0, 0, 0, 0, 0, 0, 0, 0, 0, 0, 0, 0, 0, 0, 0, 0, 0, 0, 0, 0, 0, 0, 1, 0, 64, 127, 64, 0, 0, 0, 0, 0, 1, 0, 46, 0, 64, 
39, 34, 0, 0, 0, 1, 65, 0, 31, 0, 50, 64, 64, 127, 12, 0, 0, 0, 0, 0, 0, 64, 76, 127, 6, 0, 0, 0, 0, 0, 0, 64, 52, 74, 9, 0, 0, 0, 0, 0, 0, 0, 0, 0, 0, 0, 0, 0, 0, 0, 0, 0, 0, 0, 0, 0, 0, 0, 0, 0, 0, 0, 0, 0, 0, 0, 0, 0, 0, 0, 110, 0, 2, 0, 0, 0, 0, 0, 0, 0, 0, 0, 0, 0, 0, 0, 0, 0, 0, 0, 0, 0, 0, 0, 0, 0, 0, 0, 0, 0, 0, 0, 0, 0, 0, 0, 0, 0, 0, 0, 0, 0, 0, 1, 94, 64, 127, 64, 0, 0, 0, 0, 0, 1, 11, 31, 5, 0, 
39, 34, 0, 1, 0, 1, 65, 0, 31, 0, 0, 64, 64, 127, 12, 0, 0, 0, 0, 0, 46, 64, 76, 127, 6, 0, 0, 0, 0, 0, 30, 64, 52, 74, 9, 0, 0, 0, 0, 0, 0, 0, 0, 0, 0, 0, 0, 0, 0, 0, 0, 0, 0, 0, 0, 0, 0, 0, 0, 0, 0, 0, 0, 0, 0, 0, 0, 0, 0, 0, 110, 0, 2, 0, 0, 0, 0, 0, 0, 0, 0, 0, 0, 0, 0, 0, 0, 0, 0, 0, 0, 0, 0, 0, 0, 0, 0, 0, 0, 0, 0, 0, 0, 0, 0, 0, 0, 0, 0, 0, 0, 0, 0, 1, 94, 64, 127, 64, 0, 0, 0, 0, 0, 1, 11, 31, 5, 0, 
39, 34, 0, 1, 0, 0, 56, 0, 31, 0, 0, 64, 64, 80, 12, 0, 0, 0, 1, 0, 0, 64, 76, 127, 6, 0, 0, 0, 0, 0, 13, 64, 52, 74, 9, 72, 0, 0, 0, 0, 0, 0, 0, 0, 0, 0, 0, 0, 0, 0, 0, 0, 0, 0, 0, 0, 0, 0, 0, 0, 0, 0, 0, 0, 0, 0, 0, 0, 0, 0, 101, 0, 2, 0, 0, 0, 0, 0, 0, 0, 0, 0, 0, 0, 0, 0, 0, 0, 0, 0, 0, 0, 0, 0, 0, 0, 0, 0, 0, 0, 0, 0, 0, 0, 0, 0, 0, 0, 0, 0, 0, 0, 0, 1, 94, 64, 127, 64, 0, 0, 0, 0, 0, 1, 11, 31, 5, 0, 
39, 34, 0, 0, 0, 0, 56, 0, 31, 0, 0, 63, 64, 127, 9, 87, 0, 0, 1, 0, 0, 64, 76, 127, 2, 83, 0, 3, 0, 0, 0, 64, 52, 74, 9, 46, 0, 3, 0, 0, 0, 0, 0, 0, 0, 0, 0, 0, 0, 0, 0, 0, 0, 0, 0, 0, 0, 0, 0, 0, 0, 0, 0, 0, 0, 0, 0, 0, 0, 0, 101, 0, 2, 0, 0, 0, 0, 0, 0, 0, 0, 0, 0, 0, 0, 0, 0, 0, 0, 0, 0, 0, 0, 0, 0, 0, 0, 0, 0, 0, 0, 0, 0, 0, 0, 0, 0, 0, 0, 0, 0, 0, 0, 1, 94, 64, 127, 64, 0, 0, 0, 0, 0, 1, 11, 31, 5, 0, 
39, 34, 0, 1, 47, 0, 87, 0, 0, 3, 10, 63, 64, 127, 0, 119, 0, 0, 1, 0, 0, 64, 76, 86, 12, 83, 0, 3, 0, 0, 0, 64, 52, 127, 9, 46, 0, 3, 0, 0, 0, 0, 0, 0, 0, 0, 0, 0, 0, 0, 0, 0, 0, 0, 0, 0, 0, 0, 0, 0, 0, 0, 0, 0, 0, 0, 0, 0, 0, 0, 49, 0, 3, 0, 0, 0, 0, 0, 0, 0, 0, 0, 0, 0, 0, 0, 0, 0, 0, 0, 0, 0, 0, 0, 0, 0, 0, 0, 0, 0, 0, 0, 0, 0, 0, 0, 0, 0, 0, 0, 0, 0, 0, 1, 94, 64, 127, 64, 0, 0, 0, 0, 0, 1, 11, 31, 5, 0, 
39, 34, 0, 0, 47, 0, 96, 0, 0, 3, 10, 63, 64, 127, 0, 92, 0, 0, 1, 0, 0, 64, 76, 86, 12, 83, 0, 3, 0, 0, 55, 88, 52, 51, 9, 12, 0, 1, 0, 0, 0, 0, 0, 0, 0, 0, 0, 0, 0, 0, 0, 0, 0, 0, 0, 0, 0, 0, 0, 0, 0, 0, 0, 0, 0, 0, 0, 0, 0, 0, 49, 0, 3, 0, 0, 0, 0, 0, 0, 0, 0, 0, 0, 0, 0, 0, 0, 0, 0, 0, 0, 0, 0, 0, 0, 0, 0, 0, 0, 0, 0, 0, 0, 0, 0, 0, 0, 0, 0, 0, 0, 0, 0, 1, 94, 64, 127, 64, 0, 0, 0, 0, 0, 1, 11, 31, 5, 0, 
39, 34, 0, 1, 47, 0, 96, 0, 0, 3, 10, 63, 64, 127, 0, 92, 0, 0, 1, 0, 0, 64, 76, 86, 12, 83, 0, 3, 0, 0, 55, 88, 52, 51, 9, 12, 0, 1, 0, 0, 0, 0, 0, 0, 0, 0, 0, 0, 0, 0, 0, 0, 0, 0, 0, 0, 0, 0, 0, 0, 0, 0, 0, 0, 0, 0, 0, 0, 0, 0, 49, 0, 3, 0, 0, 0, 0, 0, 0, 0, 0, 0, 0, 0, 0, 0, 0, 0, 0, 0, 0, 0, 0, 0, 0, 0, 0, 0, 0, 0, 0, 0, 0, 0, 0, 0, 0, 0, 0, 0, 0, 0, 0, 1, 94, 64, 127, 64, 0, 0, 0, 0, 0, 1, 11, 31, 5, 0};
}
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

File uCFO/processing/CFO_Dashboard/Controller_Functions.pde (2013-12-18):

String[] knobName = { "FREQ1",
                      "SEMI1",
                      "DETUNE1",
                      "GAIN1",
                      "WAVE1",
                      "FM1",
                      "FREQ2",
                      "SEMI2",
                      "DETUNE2",
                      "GAIN2",
                      "WAVE2",
                      "FM2",
                      "FREQ3",
                      "SEMI3",
                      "DETUNE3",
                      "GAIN3",
                      "WAVE3",
                      "FM3",
                      "ATTACK",
                      "DECAY",
                      "SUSTAIN",
                      "RELEASE"
                    };
                    
String[] controllerName = {   "freq1",
                              "semi1",
                              "detune1",
                              "gain1",
                              "wave1",
                              "fm1",
                              "freq2",
                              "semi2",
                              "detune2",
                              "gain2",
                              "wave2",
                              "fm2",
                              "freq3",
                              "semi3",
                              "detune3",
                              "gain3",
                              "wave3",
                              "fm3",
                              "attack",
                              "decay",
                              "sustain",
                              "release"
                            };
                              

                    
String[] waveform = { "SINE",
                      "SQUARE",
                      "PULSE",
                      "TRIANGLE",
                      "SAW",
                      "FUZZ",
                      "DIGI1",
                      "DIGI2",
                      "DIGI3",
                      "DIGI4",
                      "NOISE",
                      "DIGI6",
                      "TAN1",
                      "TAN2",
                      "TAN3",
                      "TAN4"
                    };
                    
Knob freq1,semi1,detune1,gain1,wave1,fm1,freq2,semi2,detune2,gain2,wave2,fm2,freq3,semi3,detune3,gain3,wave3,fm3,attack,decay,sustain,release;
Knob[] knobs = {freq1,semi1,detune1,gain1,wave1,fm1,freq2,semi2,detune2,gain2,wave2,fm2,freq3,semi3,detune3,gain3,wave3,fm3,attack,decay,sustain,release};

int[] knobMin =   {  0,-24,  0,  0,  0,  0,  0,-24,  0,  0,  0,  0,  0,-24,  0,  0,  0,  0,  0,  0,  0,  0};
int[] knobMax =   {127, 24,127,127, 15,127,127, 24,127,127, 15,127,127, 24,127,127, 15,127,127,127,127,127};
int[] knobValue = { 40,  0, 64,127,  2,  0, 40,  7, 64,127,  3,  0, 40,-12, 64,127,  5,  0, 12, 96, 64, 72};
int[] knobMidiCC= { 10, 11, 12, 13, 14, 15, 20, 21, 22, 23, 24, 25, 30, 31, 32, 33, 34, 35,114,115,116,117};
int numKnobs = knobValue.length;


int posX = 20;
int posY = 20;
int posEnvSpacer = 40;
int posW = 65;
int posH = 70;
int knobS = 40;
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

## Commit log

2011-05-18 IMAC code and MFRU edition hardware
    [CFO rev 1.4_dviid_jsr.brd, CFO rev 1.4_dviid_jsr.sch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]
2011-10-07 tracker software now listens to incoming MIDI
    the tracker is now listening for incoming MIDI on for instance the IAC
    driver in OS X. incoming MIDI is forwarded as serial commands to the CFO
2011-10-08 .pdf files for lasercutting acrylic casing added
    the .pdf files include several layers and are illustrator editable
2011-10-08 added bill of materials to eagle files
2011-10-08 picture explaining button layout and controls
2013-12-18 Changed folder structure to reflect CFO family
    [CFO rev 1.4_dviid_jsr.brd, CFO rev 1.4_dviid_jsr.sch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]
2013-12-19 disabled filter to free up cycles, added cheatsheet
2014-03-07 Changed SPI method and upped sample rate to 48KHz
2014-04-02 sensor test sketch
    w/ processing graphing sketch
2014-04-03 Added eagle and gerber files
    [T3HornetV2.GBL, T3HornetV2.GBO, T3HornetV2.GBP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]
2014-04-19 fixed malloc / memset in Sampler
2014-06-14 Sequencer sample added to experimental
2014-06-15 added assembly instructions
2014-06-15 put comments to assembly tutorial in txt file
2014-06-23 updated sequencer, added manual, updated assembly instructions
2014-06-25 updated sequencer, moved to official examples, updated assembly instruction
2014-06-28 updated manual and added BOM
    [BOM.xlsx]
2014-07-07 added earlier stages of other filter types.
    other filter types not ready yet
2014-07-24 added new filter type
2014-07-28 added note on uploading code to teensy based CFOs to documentation
2014-08-08 Added type of resonance to LP24 filter implementation
2014-10-04 updated documentation + BOM for 3-button version
    [BOM 3 button version.xlsx]
2014-10-14 reworked navigation for 2 button BODYSEQ
    [MIDI_functions.ino, haarnet_lydgalleriet.ino]
2014-10-15 cleaned up sequencer code, 2 versions working
    much better interaction. support for both 2 and 3 button version.
2014-10-15 cleaned up and updated documentation
    [BOM 3 button version.xlsx, BOM.xlsx]
2014-10-20 Updated uCFO to work with newer code (filters, etc)
2014-11-04 Added CFO_BODYSEQ_v2b gerber files
    and updated the sequenced_audio examples in uCFO examples folder
    [CFO_BODYSEQ_v2b.GBL, CFO_BODYSEQ_v2b.GBO, CFO_BODYSEQ_v2b.GBS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]
2014-12-29 new experimentals
    arpeggiator and MIDI controller
    [BOM 3 button version.xlsx, BOM.xlsx]
2015-01-12 BOM 2 button version small fixes
    [BOM.xlsx]
2015-08-08 added samples - try sampler sketch in examples folder
2015-09-04 uploaded new samples
    [CFO_BODYSEQ_v3.gbl, CFO_BODYSEQ_v3.gbo, CFO_BODYSEQ_v3.gbp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]
2015-09-28 SAMPLER IS HERE!!!!! FIRE IT UP!!!!!
2015-09-30 copy track, clear track, chain track, EEPROM, bit crusher
2016-04-05 small stuffs, LED feedback on MIDI note in (added, then uncommented)
2018-04-11 insert control panel preview image
